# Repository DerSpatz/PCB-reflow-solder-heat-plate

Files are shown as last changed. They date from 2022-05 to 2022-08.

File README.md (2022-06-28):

# PCB reflow solder heat plate

## Introduction

The PCB reflow solder heat plate can be used to solder small PCBs with SMD parts. The user can control the maximum temperature and heating curve.

## Hardware design

The idea for this design comes from https://github.com/AfterEarthLTD/Solder-Reflow-Plate. But when I checked the original design, I found some issues that could cause safety problems and other design choices that are not optimal.

### Feature list

- PCB size 100x100mm, heat plate size 81x69mm
- DC barrel plug (5.5x2.5mm), runs with 12V/5A power supply
- resettable 5A PTC fuse
- inrush current limiter to protect power supply when capacitors are discharged
- 2.7mF input power filter for smooth current draw
- capacitor discharging resistors
- ATMEGA4809 MCU, can be programmed via UPDI header
- high power NMOS with gate driver circuit
- flyback diode connected to the heat plate
- AMS1117 LDO
- additional diodes for protection
- dual buttons
- status LED
- 0.91" OLED display
- LMT85 analog temperature sensor as main sensor
- option to add additional digital sensors for calibration purposes

### Building your own

You can order almost all parts needed from LCSC/JLCPCB. Only the OLED display and the power supply need to be sourced elsewhere. The BOM includes LCSC part numbers for hand soldering and their automated SMT manufacturing. Minimal part size is 0805 and there's enough space between all solder pads, so hand soldering should be no problem if you have a steady hand. Hardest part will be the MCU, but this is hand solderable, too.

### Safety measures compared to the original design

The original design had a too low heat plate resistance, which caused very high current spikes when the heat plate was turned on. This should be filtered by PWM and the input capacitors, but the input capacitor in the original design was far too small (100µF). Because of this, the fuse always blew when the device was turned on, so eventually the fuse was removed again.
In my design I made the input capacitors 27 times larger to have a smoother current draw. I also added a fuse, and an inrush current limiter. After disconnecting the power supply, the output capacitors are quickly discharged to GND.
The original also had no gate driver, so the NMOS was only driven with logic levels. I added a simple NPN gate driver.
Switching inductive loads (like the long heat plate trace) causes voltage spikes. In the original design, the filtering was done with an ESD diode and a small capacitor. The usual way to filter these voltage spikes is a flyback diode.
The resistance of the heat plate was very low, so the current draw with 100% PWM duty cycle was very high. If the MCUs hangs up and the power MOSFET stays active, the original design could cause too much stress for the power supply. Furthermore, even with a hot heat plate, the resistance would still be so low that the board would draw more than 5A.
In my design, the heat plate resistance was chosen in a way that a hot heat plate will draw less than 5A, so it is much safer to run the new design, as it will automatically reach electrically safe working conditions.

## Firmware

The original firmware was reworked by Nathan Heidt (https://github.com/heidtn) and works mostly, only the temperature sensing is incorrect (as the firmware was written with an earlier board revision). So for now, you just need to unplug the device when the PCB that needed soldering is done. Also, the dual color LED is not yet included into the code, for now it just lights green to show power. And the buttons sometimes don't react properly.

Daniel Oltmanns (https://github.com/oltdaniel) is doing a rework of the firmware using platformio.

### To-do list for software:
- use of the dual color LED (green = power, orange = heating, red = hot)
- better temperature sensing
- better working buttons
- calibration function for the analog temperature sensor by taping a digital probe directly to the heat plate

Please note that I can only do hardware design, so I can't contribute anything to the software. 

### Programming the MCU

The MCU can be programmed with JTAG2UPDI (https://github.com/ElTangas/jtag2updi). For programming, you need an Arduino with ATMEGA328p (Uno or Nano), some wires, a 4.7k resistor and  a 10µF capacitor or 120 Ohm resistor to disable the auto-reset.

JCM from the Discord explained the process pretty good:

> 1. Download/Clone this project: https://github.com/ElTangas/jtag2updi and rename the folder "source" to "jtag2updi" (otherwise the Arduino IDE won't like it)
> 2. Open jtag2updi/jtag2updi.ino in your Arduino IDE
> 3. Configure the flasher options for your Arduino Nano and flash it
> 4. Connect D6 of your Arduino Nano over the 4.7kOhm resistor to the UPDI pin of the board and 5V to 5V and GND to 0V
> 5. Add the MegaCoreX hardware package to the Ardunio IDE (see https://github.com/MCUdude/MegaCoreX#how-to-install)
> 6. Install the Adafruit_GFX, Adafruit_SSD1306, DallasTemperature and Debounce2 libraries with the Library Manager (you might not need all of them depending on which firmware you plan to use)
> 7. Download and open the ino you want to upload to the ATMEGA4809 (https://github.com/DerSpatz/PCB-reflow-solder-heat-plate/blob/main/Firmware/pcb_reflow_fw/pcb_reflow_fw.ino)
> 8. Select the options for the programmer (Board: ATmega4809, Clock: Internal 16 MHz, BOD: 2.6V or 2.7V, EEPROM: retained, Pinout: 48 pin standard, Reset pin: Reset, no Bootloader) and select the port of your Ardunio Nano as Port
> 9. Select Burn Bootloader and see if it runs through
> 10. Temporarily disable auto reset for the Arduino Nano: https://playground.arduino.cc/Main/DisablingAutoResetOnSerialConnection/ (not sure if it's needed for the Nano, it was for my Mega)
> 11. Select Sketch > Upload using Programmer (normal Upload will not work)

## Thanks

Special Thanks go out to:

Nathan Heidt for writing the software and testing

Merlin Shaw (www.facebook.com/GeekIslandGaming) for ordering the first batch of prototypes and testing

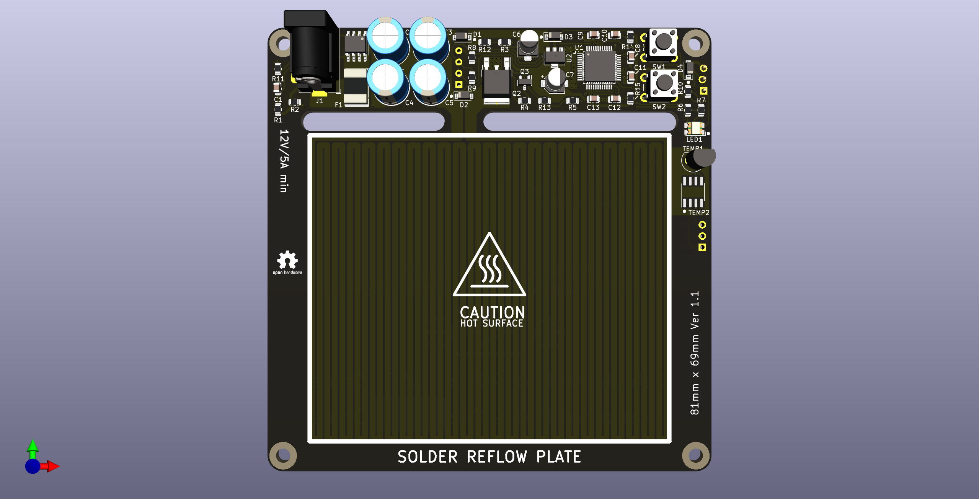
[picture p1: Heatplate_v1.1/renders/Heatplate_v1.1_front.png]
heatplate PCB front

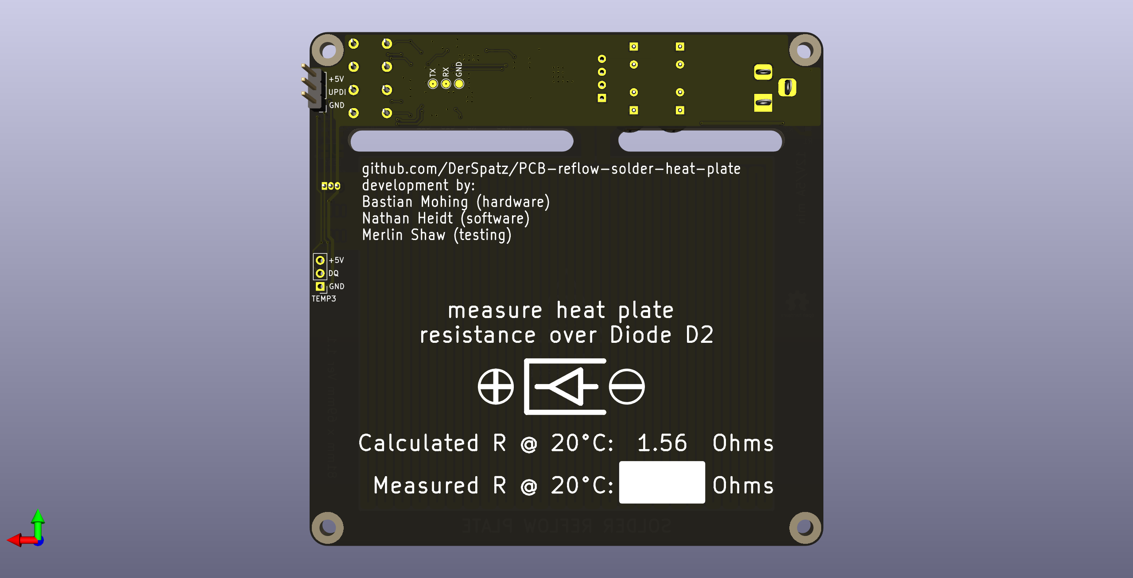
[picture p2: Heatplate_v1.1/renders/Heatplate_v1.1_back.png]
heatplate PCB back


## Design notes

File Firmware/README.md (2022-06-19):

# PCB reflow firmware
This firmware is for the PCB reflow hotplate designed by Spatz.

It has the following features:
- reflow profiles
- OLED display
- profile PID tracking
- temperature setpoint tracking
- safe voltage calculation
- memory validation 

## Build and load process
to build and load, you need a UDPI programmer and core definitions for the Atmega4809.

If you don't have a UDPI programmer you can use another arduino like in this link:
https://github.com/ElTangas/jtag2updi 

You can download the Atmega4809 definitions here:
https://github.com/MCUdude/MegaCoreX/tree/master

Make sure the DallasTemperature and Adafruit display libraries are installed. 

build and load through the arduino IDE as normal.  Select the Atmega4809 as the target
and make sure the correct programmer is selected.

## TODO

- Needs a good amount of cleanup and refactoring
- Has a hack estimation for minimum PWM, need to find a way to improve this
- should switch buttons to bounce2
- if there's no current sense, write a function to approximate resistance based on temperature
- validate temperature estimation function is correct across multiple boards

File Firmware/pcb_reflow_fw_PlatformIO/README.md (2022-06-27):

# Firmware

This firmware project structure is based on [PlatformIO](https://platformio.org/).
The flashing has been configured to use an Arduino as a programmer using the
following project: https://github.com/ElTangas/jtag2updi.

## Todo

- [ ] Split main file into multiple ones _(makes it easier to work on)_
- [ ] Better Instructions for flashing.

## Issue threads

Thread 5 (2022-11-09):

Idea: use an NTC thermistor for sensing the heat-plate temperature

DominikPalo, 2022-11-09:
The current design uses an LMT85 analog temperature sensor as the main sensor. As this sensor is not directly attached to the heated area (and can't be due to its limited temperature range –50°C to 150°C), the temperature measurements are not very precise and tend to be skewed/affected by the airflow around the sensor.

So, my idea is to use a 100K NTC thermistor instead. The thermistor would be attached directly to the bottom side of the heating area (by a piece of Kapton tape). Such NTC thermistors are very popular in 3D printers for sensing both the hot end and heated bed temperatures and therefore cheap and widely available. They are precise and can easily measure temperatures up to 300°C, so I think they would be a right fit for this project too.

The connection to the MCU is very simple - just a couple of resistors and a capacitor connected to a single ADC input. Here is an example connection from the [BTT SKR Mini E3 board](https://github.com/bigtreetech/BIGTREETECH-SKR-mini-E3/blob/master/hardware/BTT%20SKR%20MINI%20E3%20V1.2/BTT%20SKR%20mini%20E3%20V1.2sch.pdf):
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

gifter77, 2023-03-19:
It's pretty easy to do without any change to the PCB. Just connect your NTC thermistor between temp3 data and GND pins, optionally change R10 to something that works better as a resistance divider with your thermistor and change the temperature calculation code.
See how I have done it below. I'm using a 10K 3950 thermistor and I've changed R10 to 1k instead of 4.7K to get a better range in the ADC.
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

jgoldwein, 2023-03-20:
Great idea.  Have you changed the code too?  If so, what changes did you make?

VTeselkin, 2023-05-18:
Great idea, has anyone made changes to the code?

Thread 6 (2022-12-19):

Are drain and source of inrush limiter mosfet reversed?

MRo47, 2022-12-19:
thanks for sharing this.
I'm a newbie on mosfets. But should the drain and source of inrush limiter mosfet be reversed? I've read it doesn't matter much but unsure.
Or is there a good reason why they are kept as such?
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

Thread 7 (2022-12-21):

Make Centroid (Pick and Place) files available

Tyler135441, 2022-12-21:
For some reason I am unable to open the Kicad project to create a centroid file as I am not sure how to get it from github in a non text file format. Kicad is new to me so this may be my issue, but I still think it is a good idea to upload some centroid/pickandplace files in the form of a csv file for easily getting it pre soldered from pcb manufacturers like PCBWay or JLPCB.

Tyler135441, 2023-01-17:
For some reason when I downloaded the whole project natively the kicad files seemed to be corrupted or something and would not open in kicad, however when I downloaded on a separate device and moved it over via usb drive they seem to be fine. I have no idea. I still think having the centroid files in a csv on the repository would be nice though since it may circumvent any similar witchcraft in the future and simply provide greater ease of access.

Closed 2023-01-17.

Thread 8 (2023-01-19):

Low resistance Heatplates - not getting hot

ManCloud, 2023-01-19:
Hello,

I have a little Problem: i ordered 15 boards qt JLCPCB and they all seem to have too low resistance values.
I measured boards with about 1.34 ohms which work kinda fine but also have boards at 1.12ohms that do not.

If i put the resistance inside the firmware to 1.10ohm, the board will heat up until about 70°C and then constantly reduce the current until about 250mA and that's it...

and it i put the resistance to 1.12 ohm the board will surpass the 5A mark, which somehow makes my PSU shutting down (even though the >1.34ohm boards also surpass 5A but without shutting down).

I'm kinda clueless where to start debugging here 😅

This was part of a "community order" and not a "for profit thing".

bwack, 2023-02-24:
How is it going with the project. I'm about to build this myself. No expereince, though did you measure using a four wite technique? (Two wires Pass a constant current, two wires measure voltage)

ManCloud, 2023-02-24:
No, I modified a resistance meter I used in the past for coil resistance measurements for my vape

bwack, 2023-02-24:
I don't see any replies from the maintainer here. Maybe I can have a look at the code this weekend.

ManCloud, 2023-02-24:
That would be nice! I already wanted to have a look myself but am pretty busy with other stuff 🙈

bwack, 2023-03-03:
I'm experiencing overcurrent. I'm feeding in 12V from my lab power supply set to limit current at 5A. It doesn't take long for the regulator to go beyond that limit.
I've had no luck in getting the serial debugging data, so I display the PWM value on the screen in real time. It shows that the PWM value drops down to 0 (100% power)  after just a few maybe 10 seconds.. 12V into ~1 Ohm is way too much.
Not sure what to do about this yet. The board does monitor the input voltage. I could try in software to find out what how low PWM can get before the supply voltage starts to drop, with consideration that cable and contacts will drop a lot of voltage as well.

bwack, 2023-03-07:
My video on this board. https://youtu.be/bX83ZVMr6Pg

Findings. Resistance is too low to produce heat up quick enough at sensible current levels (5A). This cannot be fixed without reducing the trace width, or putting more current into and removing the 5A PTC fuse. There is no current sensing.

 It goes way beyond 5A. My bench powersupply droppet the voltage to 7V at 5A constant current  though rised to 10V when melting tin hot. But slowly. The 7V drops to about 6V at the heating bed.

I was thinking of doing my own board by tuning the heatbed to accept 24 or perhaps 19V (60W lsptop PSUs) to get the current down to 3 or 2.5A. Adding current sense. Measure resistance of the bed in real time to calculate temperature. But people are too negative, and so limited use case, I don't bother with this project I think.

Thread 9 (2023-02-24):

Tempted to start: is someone working on the issues on the to-do-list? Just to know.. Many thanks!

ik0adr, 2023-02-24:
Many thanks!!

bwack, 2023-02-24:
I'm finally building the hotplate 1.1 after a long pause. I'll give some feedback If I find anything worth mentioning. Ps I'm planning to do a youtube video as well.

ik0adr, 2023-03-01:
I am just waiting for PCB and components.
Will appreciate youtube video!!
Cheers

ik0adr, 2023-04-03:
Hi all.
I am waiting for some components to finish the DerSpatz plate.
I do have some questions thow..
Is the firmware on GitHub doing the reflow curve control?
In readme they say the temperature sensing is incorrect..
I thought the thermistor mod would solve that.
Am I wrong?
Cheers, have a nice day

Berkays, 2023-05-21:
Feel free to check out my stm32 board implementation at [repository](https://github.com/Berkays/ReflowPlate) which should hopefully has a more organized source structure and some improvements like ntc, rotary encoder input etc.

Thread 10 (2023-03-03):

Component base for self-assembly

VTeselkin, 2023-03-03:
Hello. Ordered a fee. Some notes on the component base: capacitors C6 and C7 could be made ordinary and not smd, this would reduce the number of component suppliers for those who order them from Aliexpress, for example. The two-color LED1 is generally an extremely rare component in this size, it was easier to make two small separate LEDs. Temperature sensors could be placed on the other side of the board in the center of the table, at least one of the three.

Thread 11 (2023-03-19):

Made slight code changes to take advantage of Red LED... plus some design suggestions

jgoldwein, 2023-03-19:
Hello and thank you for this amazing project.  I have now built 5 of these, all using JLCPCB boards and LSCS components that I have been able to solder on to the boards.  I have also made some slight improvements in the firmware code which I have forked and posted at https://github.com/jgoldwein/PCB-reflow-solder-heat-plate/blob/main/Firmware/pcb_reflow_fw/pcb_reflow_fw.ino.

A few suggestions:
1. Primarily, if there were a way to **separate/detach the heating surface from the primary electronics** (not including the temperature sensor), the utility of the reflow plate would increase significantly.  I find that after about 5-10 uses the heating panel deteriorates beyond its usefulness.   And, since the Dallas 1-wire temperature sensor is not being used, replacement would only require LMT85 replacement provided that the LED and R6,7 could be moved on to the main circuit board.
2. I did see a comment suggesting substitution of parts such as 2 separate LEDs in place of the one bi-LED component.  Makes sense to me, but probably relatively easy to do without changing the PCB layout.
3. No problem from my perspective using the ATMEGA4809-AFR.  Readily available and inexpensive from many vendors such as DigiKey and Mouser in my area (USA).  Took a bit of work to figure out the UPDI programming, but a positive experience for me.

Thanks again for designing this.  It is really appreciated and has been extremely useful to me.

JG

gifter77, 2023-03-19:
I believe the heating panel deteriorates quickly because it actually gets way hotter than what the LMT85 measures. Even when set to 140C I measured over 200C on the heatplate. An easy solution is to use an NTC thermistor stuck under the heatplate instead of the LMT85.

jgoldwein, 2023-03-19:
Good idea, but I know that solder melting for reflow does not seem to occur until after 1:40 or so for solder that has a 138° melting point on my system. I think we need to factor in the r values of any material such as PCBs that are in involved.

Still, I think it would be a good idea if we could detach the heating plate and replace it easily rather than the current design. With constant heating, cooling, and reheating, I can't help but think that there will inevitably be some deterioration of the heating plate.

Thank you kindly for responding to my comment. I think again that this is a great product and just want to make it even better.

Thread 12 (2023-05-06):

How many heating cycles does the PCB survive?

manuel-rw, 2023-05-06:
Hello everyone,
I want to get into SMD soldering.
Can anyone tell me, how many cycles / thermal stress this PCB usually survives, until it deteriorates?
I know that many factors will influence this, but it would be useful to get a general idea what to expect.

Thank you!
Best regards

manuel-rw, 2023-05-09:
Hi, thanks for the reply.
Since the heating PCB is not replaceable, what endurance are you getting with the IR?
It shocked me seeing people mentioning only 5 cycles, but I'm not sure how accurate that is.

bwack, 2023-05-09:
I think the 5 cycles is due to the huge temperature swings causing it to overheat.

I haven't used mine more than maybe 10 times, but the pcb is still holding up. no warping.

bwack, 2023-05-09:
Here is a video of my experimentation with IR sensor.
https://www.youtube.com/watch?v=z8zI6PzrAY8

manuel-rw, 2023-06-06:
Thanks @bwack for answering.
I think I will stick with my hot air gun for now.
Closing this issue since it's resolved :)

Closed 2023-06-06.

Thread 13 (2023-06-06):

What package for the LM1117?

crazyelectron-io, 2023-06-06:
I'm trying to figure out what package is used for the LM1117 LDO because the SOT-223 package they usually come in is too large for the PCB footprint.
A link to an example part would be great.

Closed 2023-06-06.

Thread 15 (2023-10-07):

Open 'Discussions' for repo

platima, 2023-10-07:
Hey want to open this up so suggestions like ATmega328p compatibility can be put there, as opposed to being an issue?

For now, I'll add some 'issue' suggestions, but can move them to a discussion later.

See how I have setup https://github.com/platima/ESP32-CX-Riser/discussions as a good example. Cheers!

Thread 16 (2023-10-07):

USB-C power connector

platima, 2023-10-07:
Since USB-C is the defacto standard these days, can do 20V @ 5A, and means I don't have to buy more barrel jacks

platima, 2023-10-07:
STUSB4500 looks like a good USB-C controller, and is used by https://www.sparkfun.com/products/15801, but LCSC stock appears quite low.

onsemi FUSB302BVMPX looks like a very good alternative, with plenty of stock, and a fraction of the price.

The USB connection could also then be used for flashing the ATmega328P/4809 if you have someone modify the software to also include a bootloader, aka so it works like a jtag2updi programmer AND runs the heating firmware, since there are plenty of IOs spare.

https://github.com/ReclaimerLabs/USB-PD-Breakout has this integrated nicely already it appears!

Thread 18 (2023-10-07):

No mention of PCB type it seems

platima, 2023-10-07:
Assuming 1.6mm FR4, but I cannot see this specified anywhere. Apologies if I just missed it.

platima, 2023-10-07:
I found 1.51mm (?) FR4 specified in the PCB file, but that is definitely an odd thickness.

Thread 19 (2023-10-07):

Copper thickness on PCB not specified

platima, 2023-10-07:
The KiCad PCB setup has 0.035mm (1 oz) but that seems very thin. Although that'd create more resistance and heat, and it's much cheaper to order. Thought it best to check before ordering.

Probably worth specifying this with board thickness in the README.md

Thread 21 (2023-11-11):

Not working at all. Immediate blows the 1117

arwidcool, 2023-11-11:
Has anyone actually built this?

As soon as i give it power it blows the 1117. When i power the Atmega just from 5v it works. Double, triple and 5x checked component placement and its all per v1.1

arwidcool, 2023-11-12:
Found the issue, apparently the sot89 casings have many different pin configurations for LDO.

And the main mosfet the IRLR8726TRPBF was bad and might not be optimal.

So make sure you get the correct SOT-89 LDO and an alternate to the IRLR8726TRPBF that works is AOD4184A.

Closed 2023-11-12.

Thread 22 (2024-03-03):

Spare boards for sale here

platima, 2024-03-03:
Listed spares I had made up, at cost, for anyone that wants them: [https://shop.plati.ma/products/derspatz-pcb-solder-reflow-heat-plate-v1-1](https://shop.plati.ma/products/derspatz-pcb-solder-reflow-heat-plate-v1-1)

Podex12, 2024-03-22:
do you also sell the assembled version? if so, what's the price? from where did you send it (what country)? can you send via international EMS (or any cheap shipping)?

platima, 2024-03-22:
Nah haven't had any assembled. At a glance, they'd likely be about $30 AUD each. Shipping here is all via Australia Post, as there are no courier services this regional, so about $13 to the US international standard.

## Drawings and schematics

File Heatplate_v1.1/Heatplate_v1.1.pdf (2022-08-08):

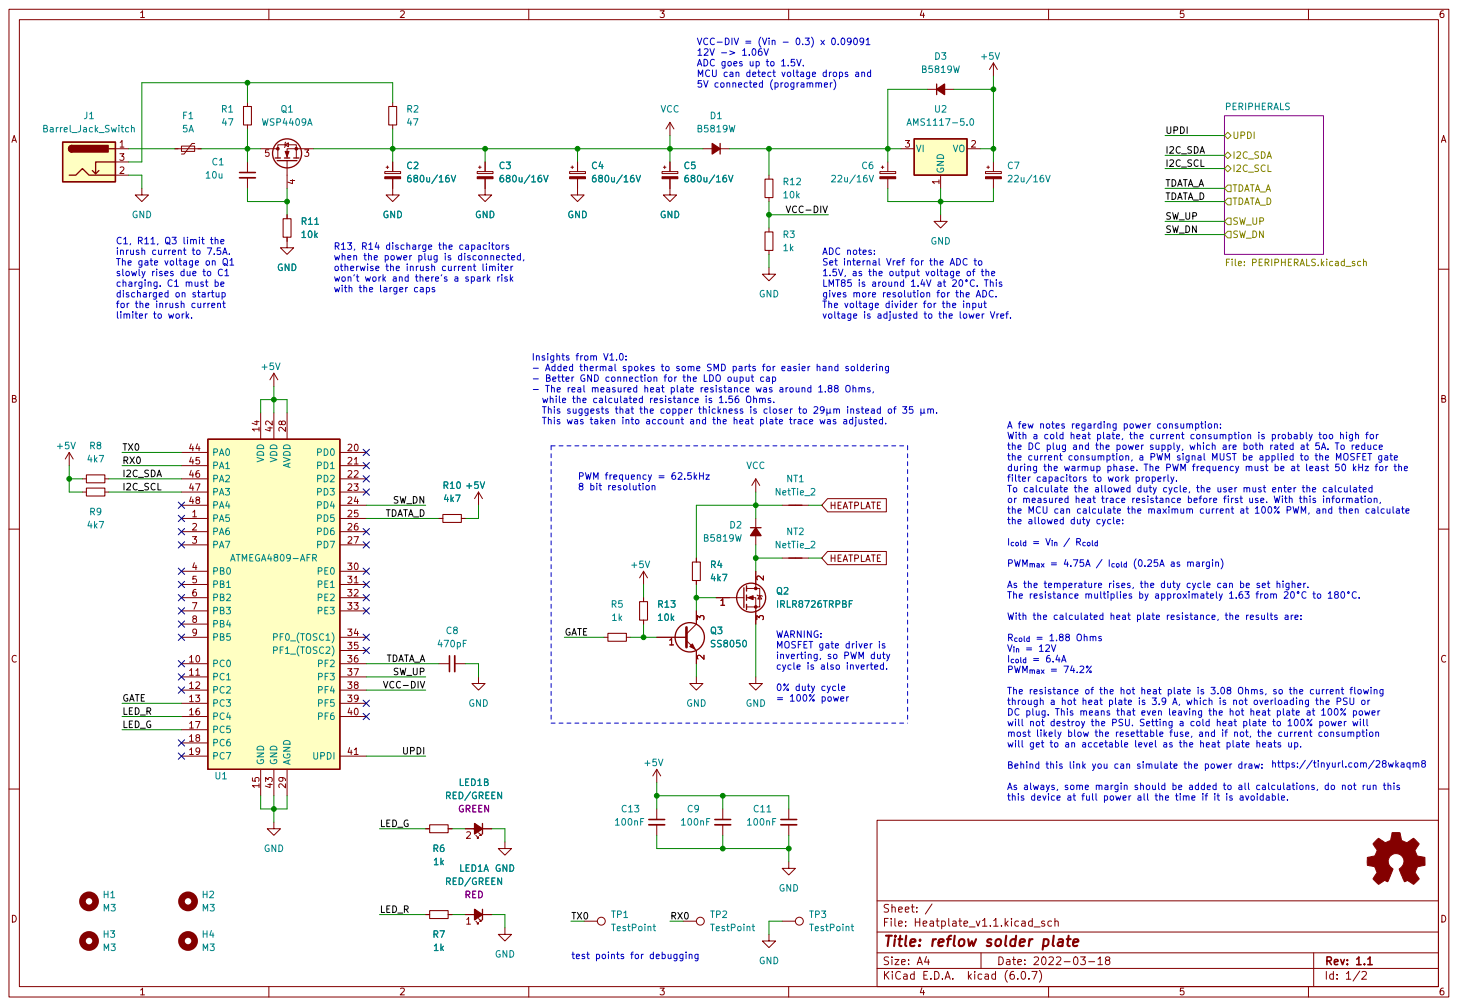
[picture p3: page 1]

VCC-DIV = (Vin - 0.3) x 0.09091
ADC goes up to 1.5V.
MCU can detect voltage drops and
5V connected (programmer)

R13, R14 discharge the capacitors
when the power plug is disconnected, otherwise the inrush current limiter won't work and there's a spark risk

This was taken into account and the heat plate trace was adjusted. C1, R11, Q3 limit the
inrush current to 7.5A. The gate voltage on Q1

ADC notes: Set internal Vref for the ADC to 1.5V, as the output voltage of the

slowly rises due to C1
charging. C1 must be
discharged on startup
for the inrush current
limiter to work.

with the larger caps

gives more resolution for the ADC.
The voltage divider for the input
voltage is adjusted to the lower Vref.

Insights from V1.0:
- Added thermal spokes to some SMD parts for easier hand soldering
- Better GND connection for the LDO ouput cap
- The real measured heat plate resistance was around 1.88 Ohms,
while the calculated resistance is 1.56 Ohms. þÿ  This suggests that the copper thickness is closer to 29µm instead of 35 µm.

A few notes regarding power consumption:
With a cold heat plate, the current consumption is probably too high for
the DC plug and the power supply, which are both rated at 5A. To reduce
the current consumption, a PWM signal MUST be applied to the MOSFET gate
during the warmup phase. The PWM frequency must be at least 50 kHz for the
filter capacitors to work properly.
To calculate the allowed duty cycle, the user must enter the calculated or measured heat trace resistance before first use. With this information,

PWM frequency = 62.5kHz 8 bit resolution

the MCU can calculate the maximum current at 100% PWM, and then calculate
the allowed duty cycle:

PWM_{max} = 4.75A / I_{cold} (0.25A as margin)

As the temperature rises, the duty cycle can be set higher.

With the calculated heat plate resistance, the results are:

this device at full power all the time if it is avoidable. WARNING: MOSFET gate driver is

inverting, so PWM duty
cycle is also inverted.

The resistance of the hot heat plate is 3.08 Ohms, so the current flowing
through a hot heat plate is 3.9 A, which is not overloading the PSU or
DC plug. This means that even leaving the hot heat plate at 100% power
will not destroy the PSU. Setting a cold heat plate to 100% power will
most likely blow the resettable fuse, and if not, the current consumption
will get to an accetable level as the heat plate heats up.

Behind this link you can simulate the power draw:

As always, some margin should be added to all calculations, do not run this

File: Heatplate_v1.1.kicad_sch Sheet: /
Id: 1/2 Title: reflow solder plate

test points for debugging

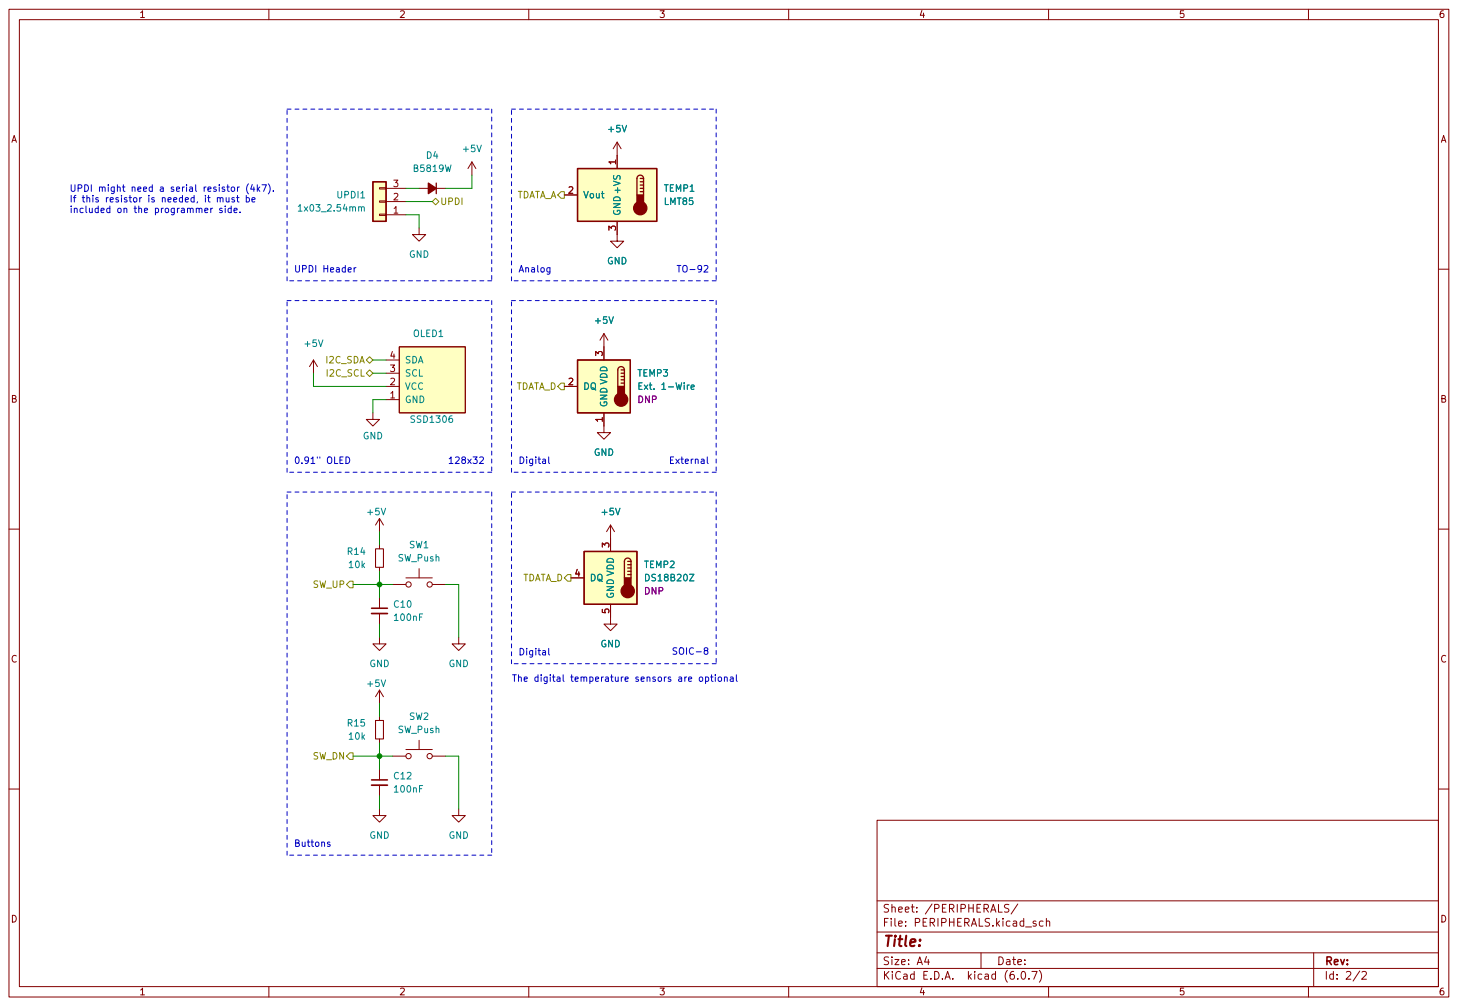
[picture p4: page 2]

UPDI might need a serial resistor (4k7).
If this resistor is needed, it must be

3 TEMP3 Ext. 1-Wire DNP VDD
TEMP3 Ext. 1-Wire DNP GND

File: PERIPHERALS.kicad_sch Sheet: /PERIPHERALS/ GND

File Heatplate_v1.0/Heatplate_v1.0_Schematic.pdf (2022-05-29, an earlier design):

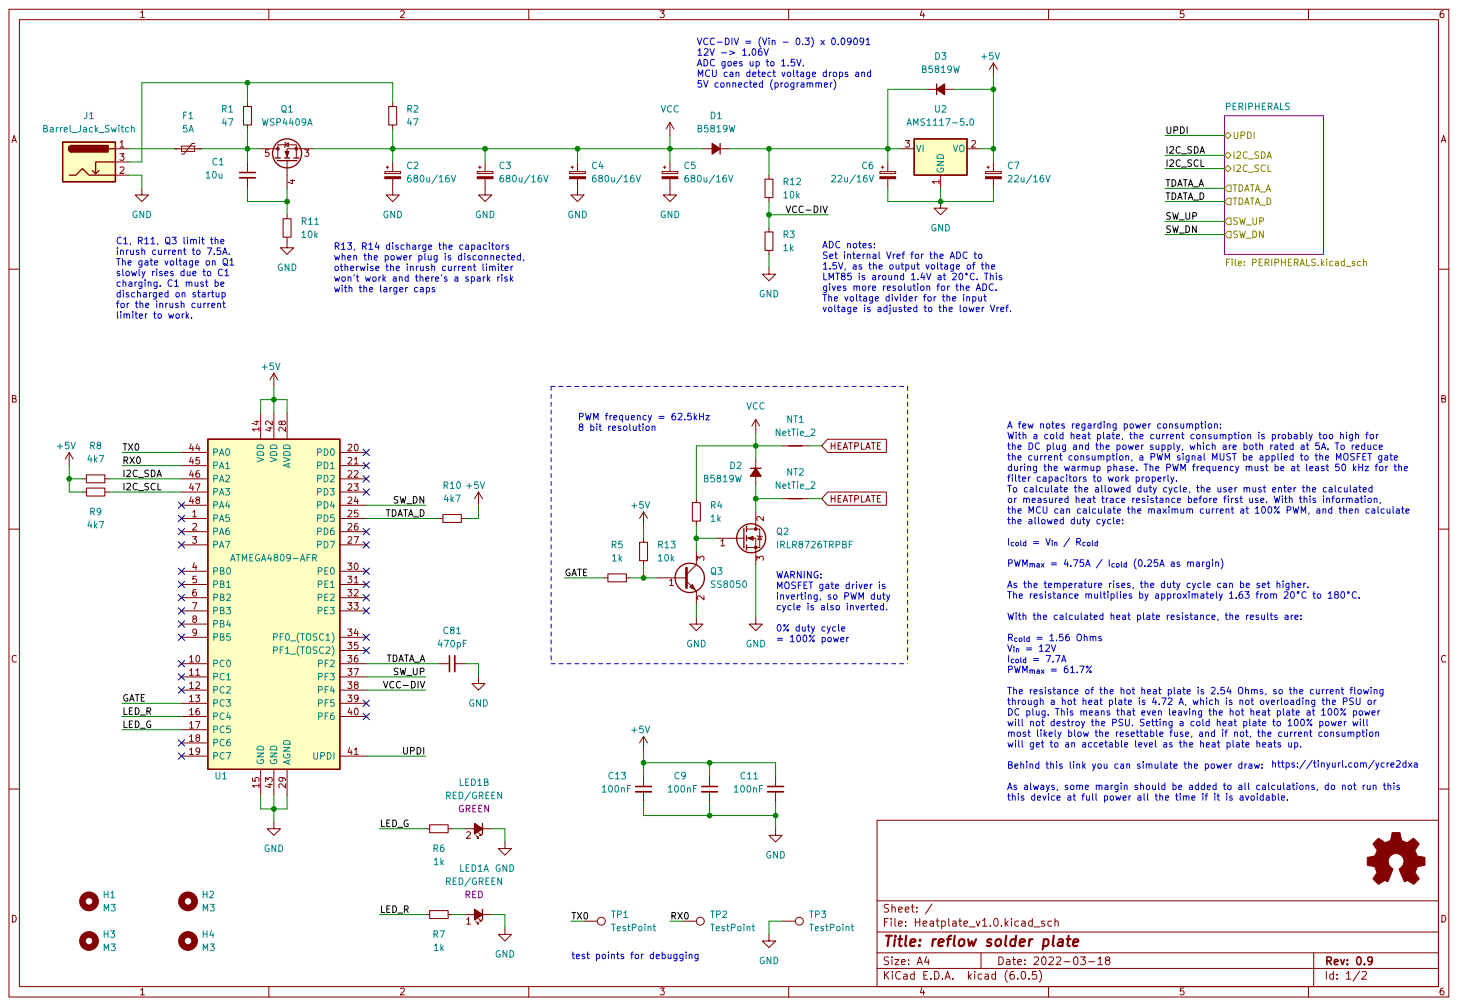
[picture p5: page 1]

VCC-DIV = (Vin - 0.3) x 0.09091
ADC goes up to 1.5V.
MCU can detect voltage drops and
5V connected (programmer)

voltage is adjusted to the lower Vref. C1, R11, Q3 limit the
inrush current to 7.5A. The gate voltage on Q1

PWM frequency = 62.5kHz 8 bit resolution R13, R14 discharge the capacitors
when the power plug is disconnected, otherwise the inrush current limiter won't work and there's a spark risk

slowly rises due to C1
charging. C1 must be
discharged on startup
for the inrush current
limiter to work.

gives more resolution for the ADC.
The voltage divider for the input

A few notes regarding power consumption:
With a cold heat plate, the current consumption is probably too high for
the DC plug and the power supply, which are both rated at 5A. To reduce
the current consumption, a PWM signal MUST be applied to the MOSFET gate
during the warmup phase. The PWM frequency must be at least 50 kHz for the
TP3 TestPoint NT2 NetTie_2 GND

filter capacitors to work properly.
To calculate the allowed duty cycle, the user must enter the calculated or measured heat trace resistance before first use. With this information,

the MCU can calculate the maximum current at 100% PWM, and then calculate
the allowed duty cycle:

PWM_{max} = 4.75A / I_{cold} (0.25A as margin)

https://tinyurl.com/ycre2dxa WARNING: MOSFET gate driver is

As the temperature rises, the duty cycle can be set higher.

inverting, so PWM duty
cycle is also inverted.

With the calculated heat plate resistance, the results are:

The resistance of the hot heat plate is 2.54 Ohms, so the current flowing
through a hot heat plate is 4.72 A, which is not overloading the PSU or
DC plug. This means that even leaving the hot heat plate at 100% power
will not destroy the PSU. Setting a cold heat plate to 100% power will
most likely blow the resettable fuse, and if not, the current consumption
will get to an accetable level as the heat plate heats up.

Behind this link you can simulate the power draw:

As always, some margin should be added to all calculations, do not run this
this device at full power all the time if it is avoidable.

File: Heatplate_v1.0.kicad_sch Sheet: /
Id: 1/2 Title: reflow solder plate

test points for debugging

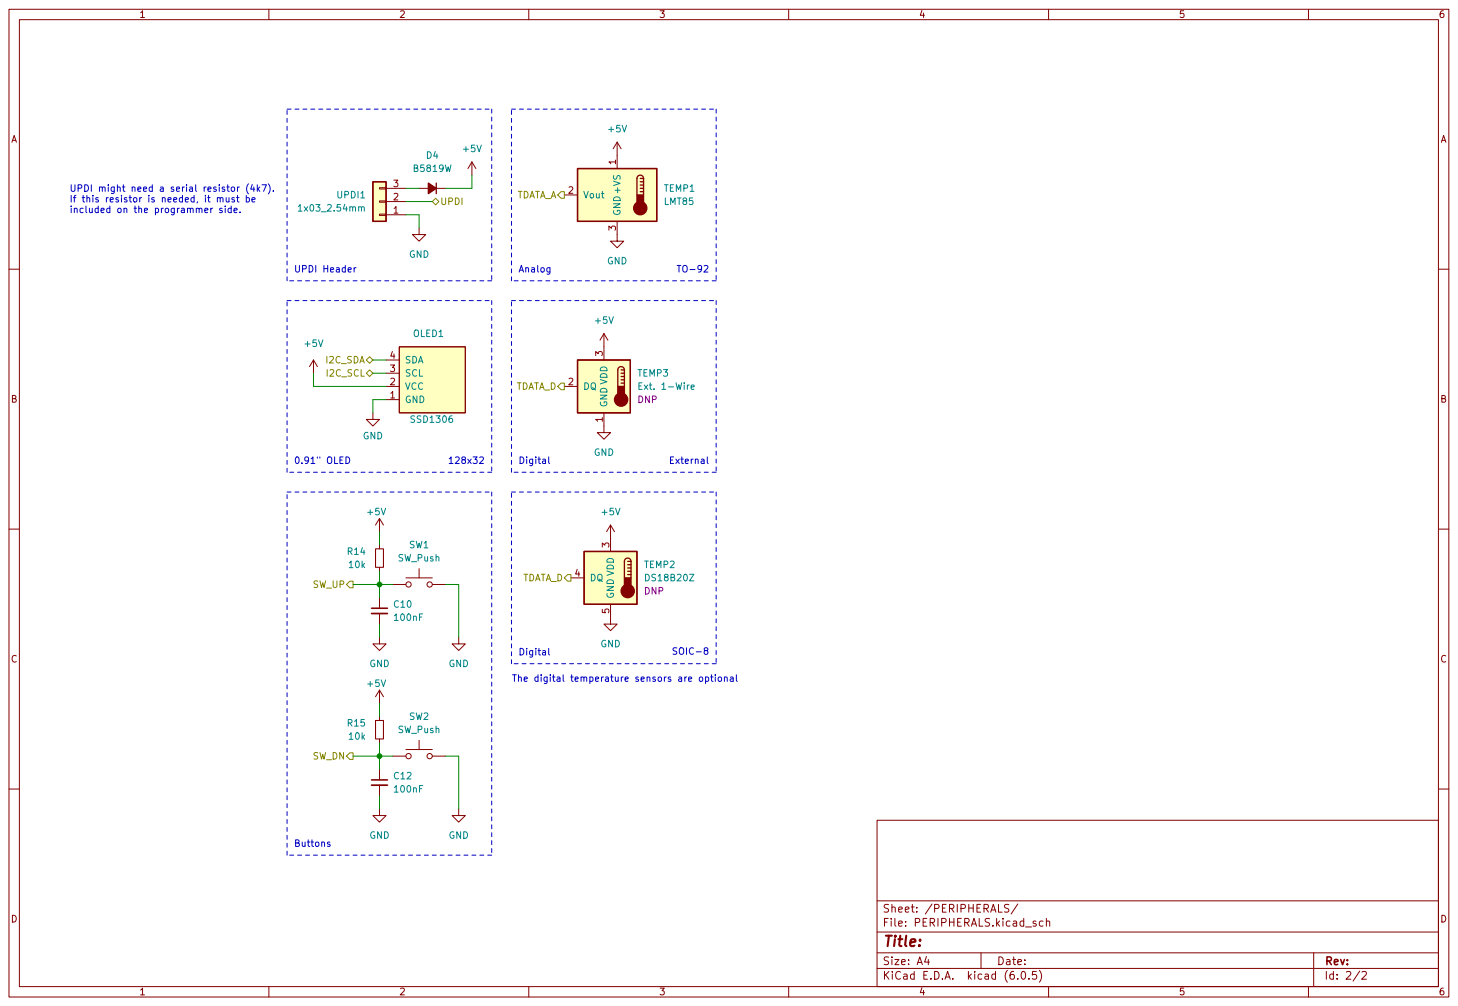
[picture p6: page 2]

UPDI might need a serial resistor (4k7).
If this resistor is needed, it must be

3 TEMP3 Ext. 1-Wire DNP VDD

File: PERIPHERALS.kicad_sch Sheet: /PERIPHERALS/ C10

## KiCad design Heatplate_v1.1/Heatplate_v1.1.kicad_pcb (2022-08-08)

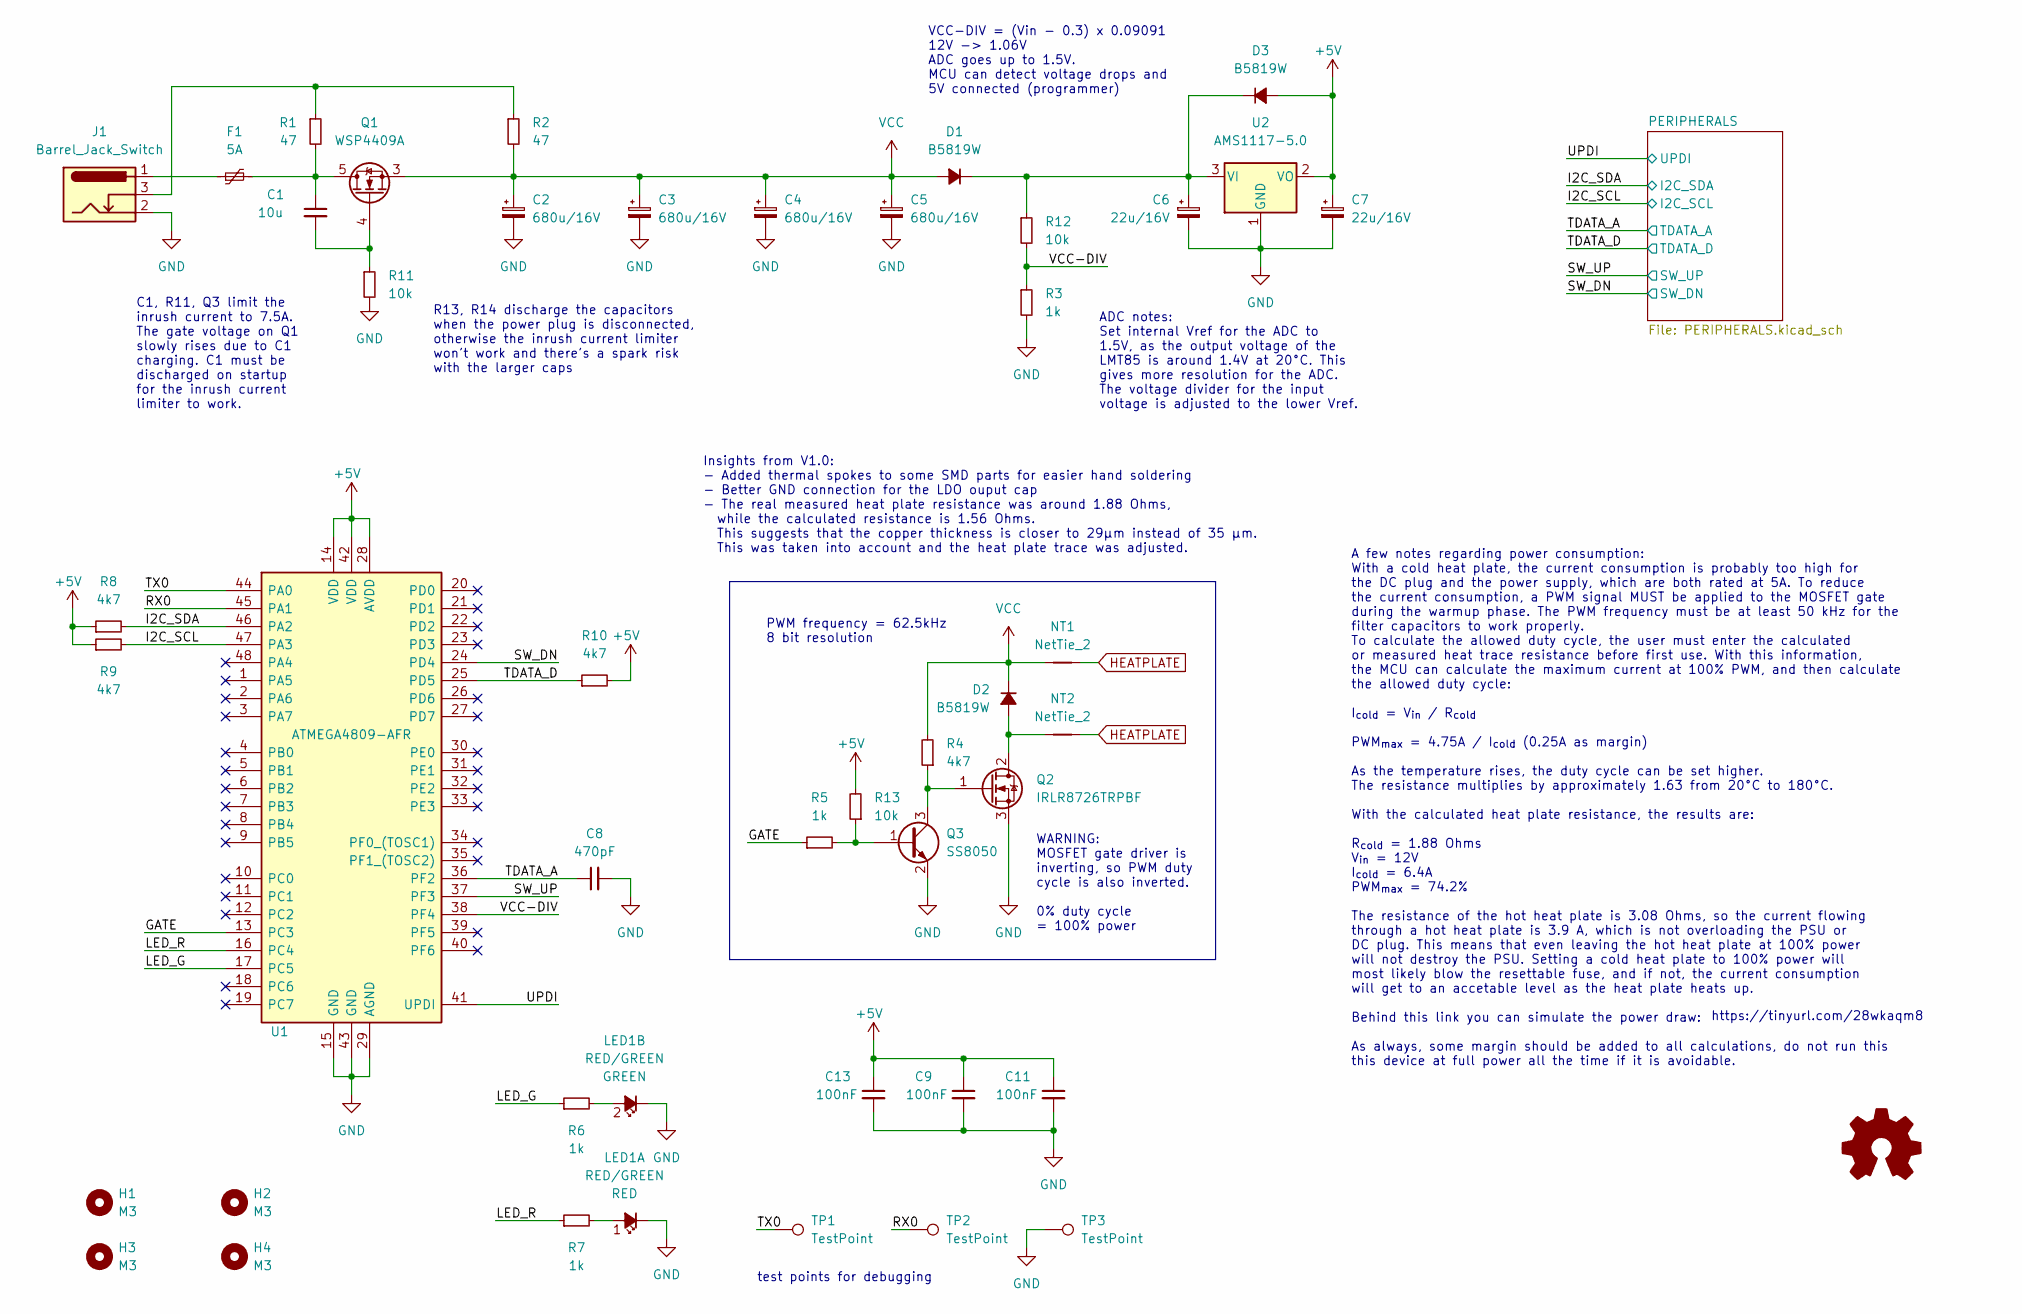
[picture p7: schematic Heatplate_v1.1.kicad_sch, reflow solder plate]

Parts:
C1: 10u; C_0805_2012Metric; LCSC Part Number C2922480
C2, C3, C4, C5: 680u/16V; CP_Radial_D8.0mm_P3.50mm; LCSC Part Number C88760
C6, C7: 22u/16V; CP_Elec_4x5.4; LCSC Part Number C88799
C8: 470pF; C_0805_2012Metric; LCSC Part Number C1743
C9, C11, C13: 100nF; C_0805_2012Metric; LCSC Part Number C1711
D1, D2, D3: B5819W; D_SOD-123; LCSC Part Number C64885
F1: 5A; Fuse_2920_7451Metric; LCSC Part Number C910846
H1, H2, H3, H4: M3; MountingHole_3.2mm_M3; LCSC Part Number C551332
J1: Barrel_Jack_Switch; BarrelJack_Horizontal; LCSC Part Number C381115
LED1: RED/GREEN; LED_Avago_PLCC4_3.2x2.8mm_CW; LCSC Part Number C131251
LOGO1: Logo_Open_Hardware_Small; OSHW-Logo2_7.3x6mm_SilkScreen
NT1, NT2: NetTie_2; NetTie-2_SMD_Pad1.3mm
Q1: WSP4409A; SOIC-8_3.9x4.9mm_P1.27mm; LCSC Part Number C2880527
Q2: IRLR8726TRPBF; TO-252-2; LCSC Part Number C81137
Q3: SS8050; SOT-23; LCSC Part Number C444722
R1, R2: 47; R_0805_2012Metric; LCSC Part Number C17714
R3, R5, R6, R7: 1k; R_0805_2012Metric; LCSC Part Number C17513
R4, R8, R9, R10: 4k7; R_0805_2012Metric; LCSC Part Number C17673
R11, R12, R13: 10k; R_0805_2012Metric; LCSC Part Number C17414
TP1, TP2, TP3: TestPoint; TestPoint_Pad_D1.5mm
U1: ATMEGA4809-AFR; TQFP-48_7x7mm_P0.5mm; Manufacturer_Part_Number ATMEGA4809-AFR; Mouser Part Number 556-ATMEGA4809-AFR
U2: AMS1117-5.0; SOT-89-3; LCSC Part Number C351450

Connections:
+5V: C7.1, C9.1, C11.1, C13.1, D3.2 (A), R8.1, R9.1, R10.2, R13.2, U1.14 (VDD), U1.28 (AVDD), U1.42 (VDD), U2.2 (VO); also elsewhere on the board
/GATE: R5.1, U1.13 (PC3)
/I2C_SCL: R9.2, U1.47 (PA3); also elsewhere on the board
/I2C_SDA: R8.2, U1.46 (PA2); also elsewhere on the board
/LED_G: R6.1, U1.17 (PC5)
/LED_R: R7.1, U1.16 (PC4)
/RX0: TP2.1, U1.45 (PA1)
/SW_DN: U1.24 (PD4); also elsewhere on the board
/SW_UP: U1.37 (PF3); also elsewhere on the board
/TDATA_A: C8.1, U1.36 (PF2); also elsewhere on the board
/TDATA_D: R10.1, U1.25 (PD5); also elsewhere on the board
/TX0: TP1.1, U1.44 (PA0)
/UPDI: U1.41 (UPDI); also elsewhere on the board
/VCC-DIV: R3.1, R12.2, U1.38 (PF4)
GND: C2.2, C3.2, C4.2, C5.2, C6.2, C7.2, C8.2, C9.2, C11.2, C13.2, J1.2, LED1.2 (K1), LED1.4 (K2), Q2.3 (S), Q3.2 (E), R3.2, R11.2, TP3.1, U1.15 (GND), U1.29 (AGND), U1.43 (GND), U2.1 (GND); also elsewhere on the board
HEATPLATE: NT1.2, NT2.2
unnamed: C1.1, F1.2, Q1.5 (D), Q1.6 (D), Q1.7 (D), Q1.8 (D), R1.2
unnamed: C1.2, Q1.4 (G), R11.1
unnamed: C6.1, D1.1 (K), D3.1 (K), R12.1, U2.3 (VI)
unnamed: D2.2 (A), NT2.1, Q2.2 (D)
unnamed: F1.1, J1.1
unnamed: J1.3, R1.1, R2.1
unnamed: LED1.1 (A1), R7.2
unnamed: LED1.3 (A2), R6.2
unnamed: Q2.1 (G), Q3.3 (C), R4.1
unnamed: Q3.1 (B), R5.2, R13.1
VCC: C2.1, C3.1, C4.1, C5.1, D1.2 (A), D2.1 (K), NT1.1, Q1.1 (S), Q1.2 (S), Q1.3 (S), R2.2, R4.2

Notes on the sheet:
C1, R11, Q3 limit the inrush current to 7.5A. The gate voltage on Q1 slowly rises due to C1 charging. C1 must be discharged on startup for the inrush current limiter to work.
VCC-DIV = (Vin - 0.3) x 0.09091 12V -> 1.06V ADC goes up to 1.5V. MCU can detect voltage drops and 5V connected (programmer)
PWM frequency = 62.5kHz 8 bit resolution
A few notes regarding power consumption: With a cold heat plate, the current consumption is probably too high for the DC plug and the power supply, which are both rated at 5A. To reduce the current consumption, a PWM signal MUST be applied to the MOSFET gate during the warmup phase. The PWM frequen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
WARNING: MOSFET gate driver is inverting, so PWM duty cycle is also inverted. 0% duty cycle = 100% power
R13, R14 discharge the capacitors when the power plug is disconnected, otherwise the inrush current limiter won't work and there's a spark risk with the larger caps
https://tinyurl.com/28wkaqm8
test points for debugging
ADC notes: Set internal Vref for the ADC to 1.5V, as the output voltage of the LMT85 is around 1.4V at 20°C. This gives more resolution for the ADC. The voltage divider for the input voltage is adjusted to the lower Vref.
Insights from V1.0: - Added thermal spokes to some SMD parts for easier hand soldering - Better GND connection for the LDO ouput cap - The real measured heat plate resistance was around 1.88 Ohms, while the calculated resistance is 1.56 Ohms. This suggests that the copper thickness is closer to 29µ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

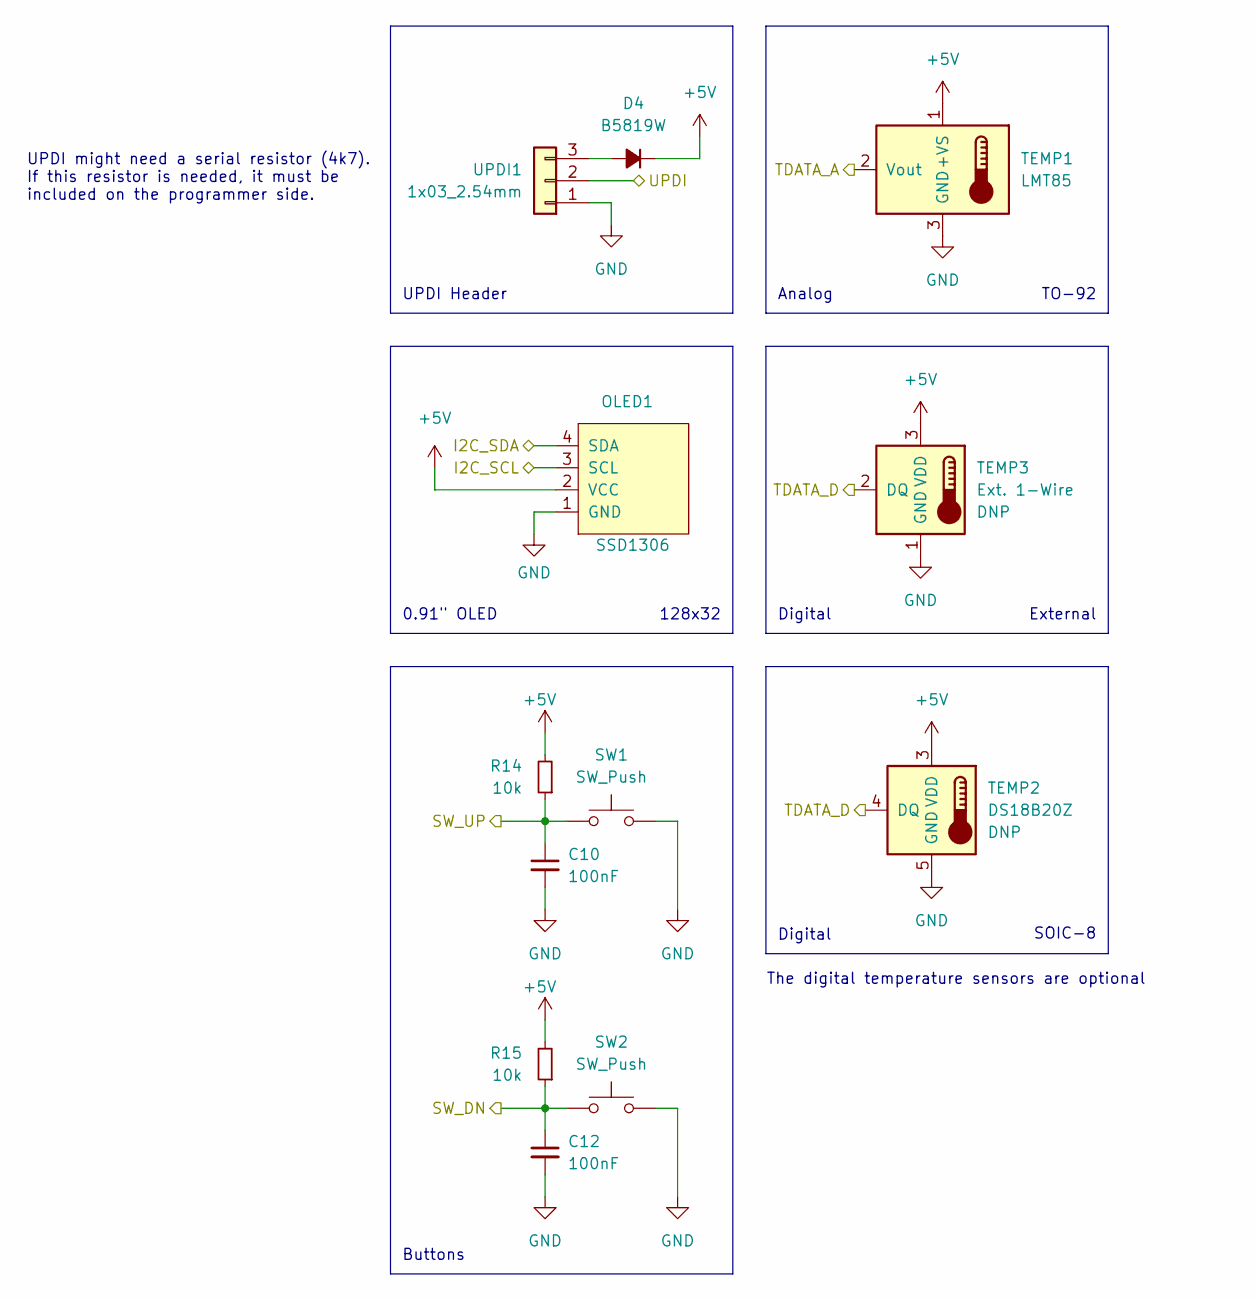
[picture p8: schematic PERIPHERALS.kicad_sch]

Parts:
C10, C12: 100nF; C_0805_2012Metric; LCSC Part Number C1711
D4: B5819W; D_SOD-123; LCSC Part Number C64885
OLED1: SSD1306; 0.91Inch-OLED-Module; LCSC Part Number C2718488
R14, R15: 10k; R_0805_2012Metric; LCSC Part Number C17414
SW1, SW2: SW_Push; SW_PUSH_6mm; LCSC Part Number C136682
TEMP1: LMT85; TO-92_Inline; LCSC Part Number C75856
TEMP2: DS18B20Z; SOIC-8_3.9x4.9mm_P1.27mm; LCSC Part Number C695837
TEMP3: Ext. 1-Wire; PinHeader_1x03_P2.54mm_Vertical
UPDI1: 1x03_2.54mm; PinHeader_1x03_P2.54mm_Vertical; LCSC Part Number C49257

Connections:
+5V: D4.1 (K), OLED1.2 (VCC), R14.2, R15.2, TEMP1.1 (+VS), TEMP2.3 (VDD), TEMP3.3 (VDD); also elsewhere on the board
/I2C_SCL: OLED1.3 (SCL); also elsewhere on the board
/I2C_SDA: OLED1.4 (SDA); also elsewhere on the board
/SW_DN: C12.1, R15.1, SW2.1; also elsewhere on the board
/SW_UP: C10.1, R14.1, SW1.1; also elsewhere on the board
/TDATA_A: TEMP1.2 (Vout); also elsewhere on the board
/TDATA_D: TEMP2.4 (DQ), TEMP3.2 (DQ); also elsewhere on the board
/UPDI: UPDI1.2; also elsewhere on the board
GND: C10.2, C12.2, OLED1.1 (GND), SW1.2, SW2.2, TEMP1.3 (GND), TEMP2.5 (GND), TEMP3.1 (GND), UPDI1.1; also elsewhere on the board
unnamed: D4.2 (A), UPDI1.3

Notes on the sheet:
SOIC-8
Digital
UPDI Header
128x32
Analog
TO-92
0.91" OLED
The digital temperature sensors are optional
Buttons
UPDI might need a serial resistor (4k7). If this resistor is needed, it must be included on the programmer side.
External

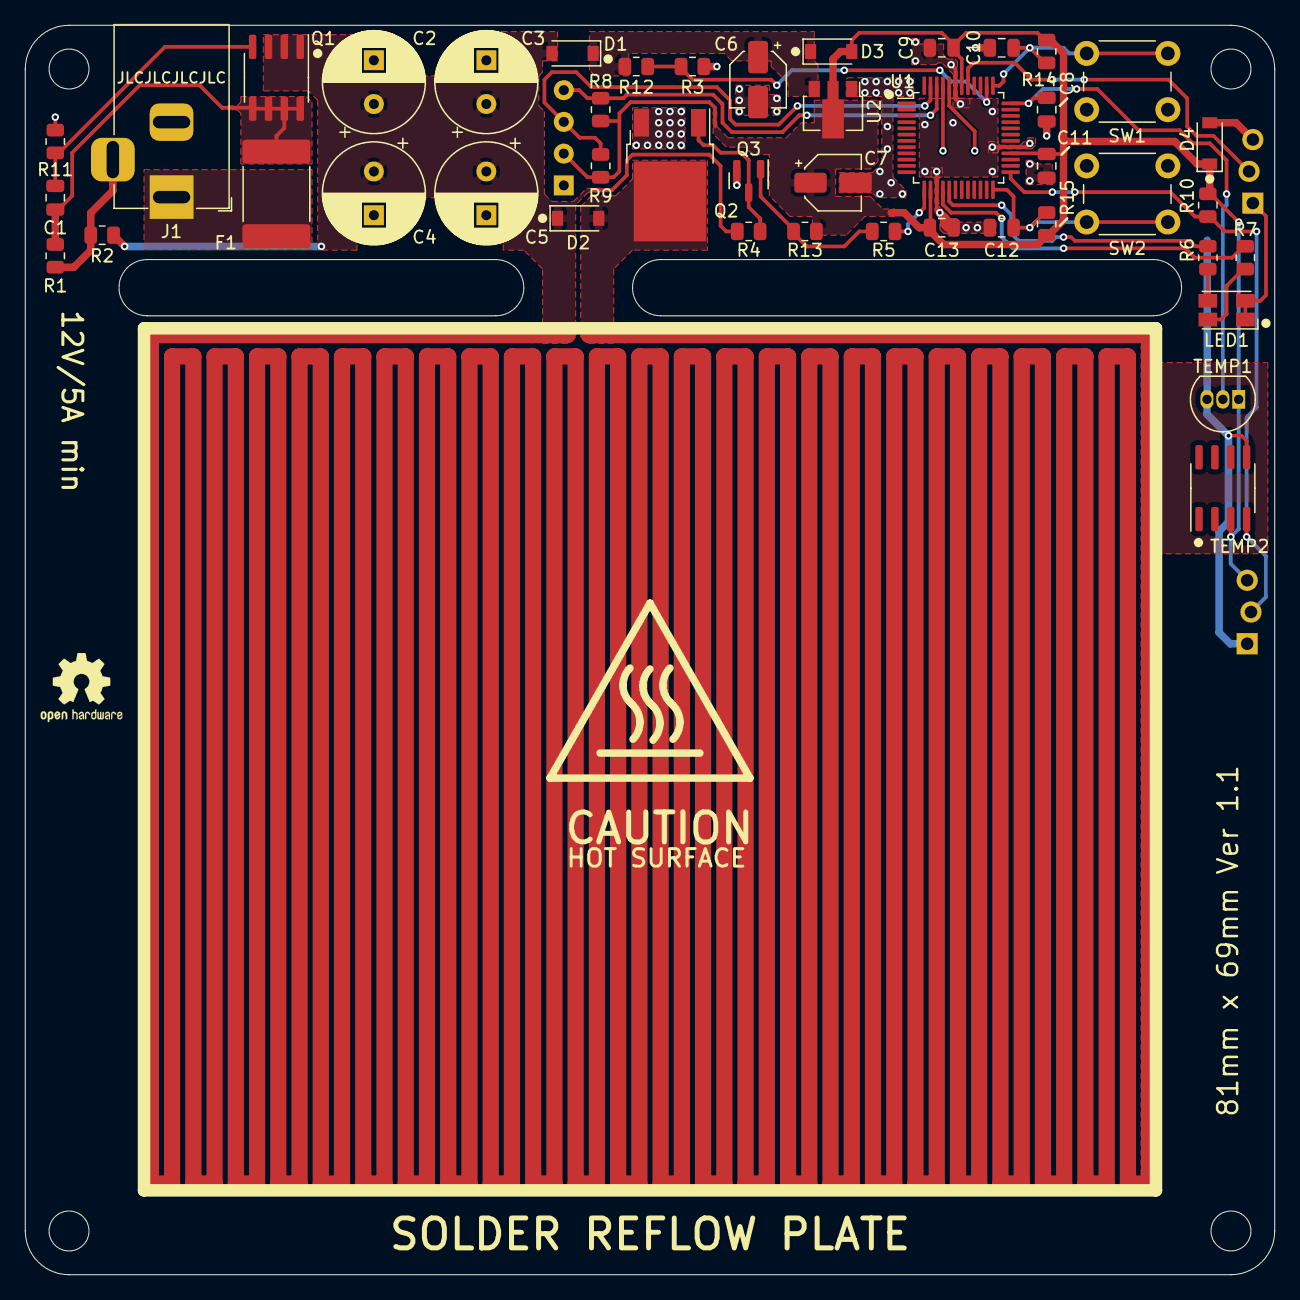
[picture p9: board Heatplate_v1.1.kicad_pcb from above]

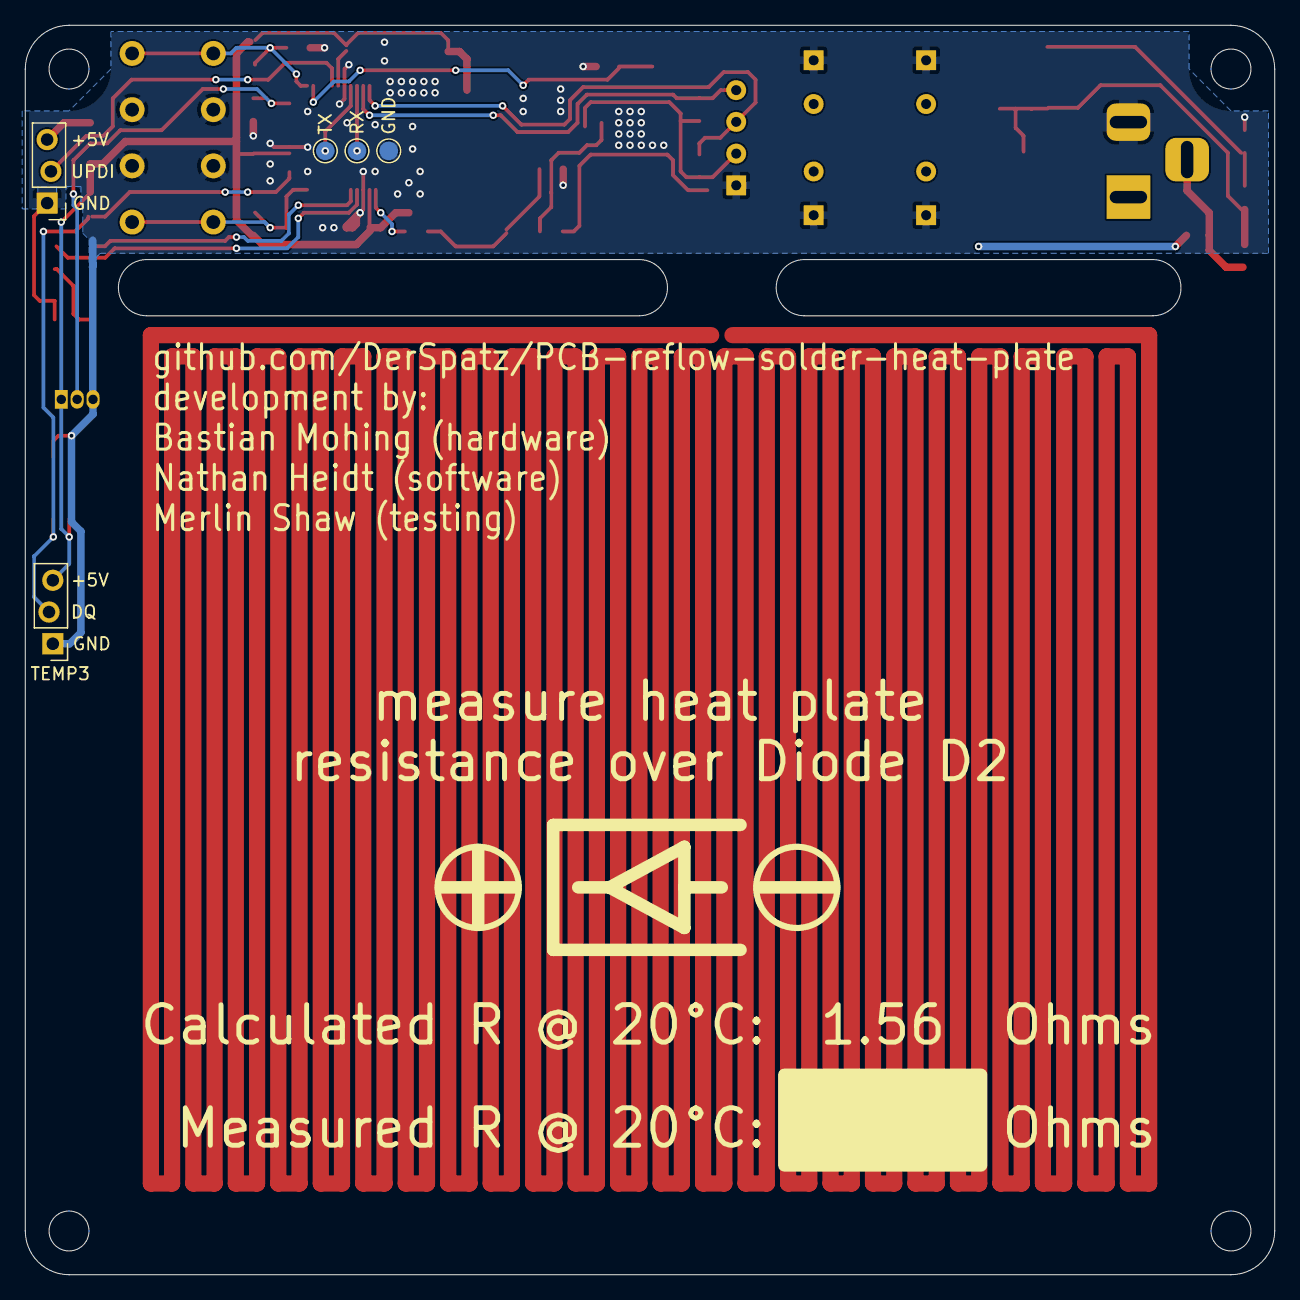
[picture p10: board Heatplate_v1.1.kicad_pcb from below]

Board: 2 copper layers, 100.0 x 100.0 mm, 57 parts (5 on the bottom side), 28 nets.

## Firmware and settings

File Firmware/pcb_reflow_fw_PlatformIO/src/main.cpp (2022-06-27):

/* Solder Reflow Plate Sketch
 *  H/W - Ver Spatz-1.0
 *  S/W - Ver 0.35
 *  by Chris Halsall and Nathan Heidt
 */

/*
 * TODOS:
 * - add digital sensor setup routine if they are detected, but not setup
 * - figure out a method for how to use all the temperature sensors
 * - implement an observer/predictor for the temperature sensors.  Kalman filter
 * time?!?
 */

#include <Adafruit_GFX.h>
#include <Adafruit_SSD1306.h>
#include <DallasTemperature.h>
#include <EEPROM.h>
#include <OneWire.h>
#include <SPI.h>

// Version Definitions
static const PROGMEM float hw = 0.9;
static const PROGMEM float sw = 0.15;

// Screen Definitions
#define SCREEN_WIDTH 128
#define SCREEN_HEIGHT 32
#define SCREEN_ADDRESS 0x3C  // I2C Address
Adafruit_SSD1306 display(SCREEN_WIDTH, SCREEN_HEIGHT, &Wire,
                         -1);  // Create Display

// Pin Definitions
#define MOSFET_PIN PIN_PC3
#define UPSW_PIN PIN_PF3
#define DNSW_PIN PIN_PD4
#define TEMP_PIN PIN_PF2  // A2
#define VCC_PIN PIN_PF4   // A0
#define LED_GREEN_PIN PIN_PC5
#define LED_RED_PIN PIN_PC4
#define ONE_WIRE_BUS PIN_PD5

#define MOSFET_PIN_OFF 255

enum menu_state_t {
  MENU_IDLE,
  MENU_SELECT_PROFILE,
  MENU_HEAT,
  MENU_INC_TEMP,
  MENU_DEC_TEMP
};
enum buttons_state_t {
  BUTTONS_NO_PRESS,
  BUTTONS_BOTH_PRESS,
  BUTTONS_UP_PRESS,
  BUTTONS_DN_PRESS
};
enum single_button_state_t {
  BUTTON_PRESSED,
  BUTTON_RELEASED,
  BUTTON_NO_ACTION
};

// Button interrupt state
volatile single_button_state_t up_button_state = BUTTON_NO_ACTION;
volatile single_button_state_t dn_button_state = BUTTON_NO_ACTION;
volatile unsigned long up_state_change_time = 0;
volatile unsigned long down_state_change_time = 0;

// Temperature Info
byte max_temp_array[] = {140, 150, 160, 170, 180};
byte max_temp_index = 0;
#define MAX_RESISTANCE 10.0
float bed_resistance = 1.88;
#define MAX_AMPERAGE 5.0
#define PWM_VOLTAGE_SCALAR 2.0

// These values were derived using a regression from real world data.
// See the jupyter notebooks for more detail
#define ANALOG_APPROXIMATION_SCALAR 1.612
#define ANALOG_APPROXIMATION_OFFSET -20.517

// EEPROM storage locations
#define CRC_ADDR 0
#define FIRSTTIME_BOOT_ADDR 4
#define TEMP_INDEX_ADDR 5
#define RESISTANCE_INDEX_ADDR 6
#define DIGITAL_TEMP_ID_ADDR 10

// Voltage Measurement Info
#define VOLTAGE_REFERENCE 1.5

// Solder Reflow Plate Logo
static const uint8_t PROGMEM logo[] = {
    0x00, 0x00, 0x00, 0x01, 0x00, 0x00, 0x00, 0x00, 0x00, 0x00, 0x00, 0x00,
    0x00, 0x00, 0x00, 0x00, 0x00, 0x00, 0x00, 0x01, 0x80, 0x00, 0x00, 0x00,
    0x00, 0x00, 0x1f, 0x00, 0x00, 0x00, 0x00, 0x00, 0x00, 0x00, 0x00, 0x01,
    0x80, 0x00, 0x00, 0x1f, 0xc0, 0x00, 0x31, 0x80, 0x00, 0x00, 0x00, 0x00,
    0x1f, 0xe0, 0x03, 0x01, 0x80, 0x00, 0x00, 0x30, 0x70, 0x00, 0x21, 0x80,
    0x00, 0x00, 0x00, 0x00, 0x10, 0x20, 0x03, 0x00, 0xc7, 0x80, 0x00, 0x20,
    0x18, 0xf0, 0x61, 0x80, 0x00, 0x00, 0x00, 0x00, 0x18, 0x00, 0x03, 0x3e,
    0xcc, 0xc0, 0xc0, 0x04, 0x19, 0x98, 0x61, 0x80, 0x00, 0x00, 0x00, 0x00,
    0x1c, 0x01, 0xf3, 0x77, 0xd8, 0xc7, 0xe0, 0x06, 0x33, 0x18, 0x61, 0x8f,
    0x88, 0x00, 0x00, 0x00, 0x06, 0x03, 0x3b, 0x61, 0xd0, 0xc6, 0x00, 0x07,
    0xe2, 0x18, 0x61, 0x98, 0xd8, 0x04, 0x00, 0x00, 0x01, 0xc6, 0x0b, 0x60,
    0xd9, 0x86, 0x00, 0x06, 0x03, 0x30, 0xff, 0xb0, 0x78, 0x66, 0x00, 0x00,
    0x40, 0xe4, 0x0f, 0x60, 0xdf, 0x06, 0x00, 0x07, 0x03, 0xe0, 0x31, 0xe0,
    0x78, 0x62, 0x00, 0x00, 0x40, 0x3c, 0x0f, 0x61, 0xd8, 0x06, 0x00, 0x07,
    0x83, 0x00, 0x31, 0xe0, 0x78, 0x63, 0x00, 0x00, 0x60, 0x36, 0x1b, 0x63,
    0xc8, 0x02, 0x00, 0x02, 0xc1, 0x00, 0x18, 0xb0, 0xcc, 0xe2, 0x00, 0x00,
    0x30, 0x33, 0x3b, 0x36, 0x4e, 0x03, 0x00, 0x02, 0x61, 0xc0, 0x0c, 0x99,
    0xcd, 0xfe, 0x00, 0x00, 0x0f, 0xe1, 0xe1, 0x3c, 0x03, 0xf3, 0x00, 0x02,
    0x38, 0x7e, 0x0c, 0x8f, 0x07, 0x9c, 0x00, 0x00, 0x00, 0x00, 0x00, 0x00,
    0x00, 0x00, 0x00, 0x00, 0x08, 0x00, 0x00, 0x00, 0x00, 0x00, 0x00, 0x00,
    0x00, 0x00, 0x00, 0x18, 0x00, 0x00, 0x00, 0x00, 0x00, 0x00, 0x00, 0x00,
    0x00, 0x00, 0x00, 0x00, 0x7f, 0x84, 0x00, 0x18, 0x00, 0x00, 0x00, 0x00,
    0x00, 0x00, 0x00, 0x00, 0x00, 0x00, 0x00, 0x00, 0xc0, 0xe4, 0x00, 0x18,
    0x38, 0x00, 0x00, 0x00, 0x00, 0x00, 0x00, 0x00, 0x00, 0x00, 0x00, 0x00,
    0x04, 0x3c, 0x3c, 0x18, 0x6c, 0x00, 0x00, 0x00, 0x00, 0x00, 0x00, 0x00,
    0x00, 0x00, 0x00, 0x00, 0x04, 0x1e, 0x06, 0x7f, 0xc6, 0x00, 0x00, 0x00,
    0x00, 0x00, 0x00, 0x00, 0x00, 0x00, 0x00, 0x00, 0x04, 0x3e, 0x03, 0x18,
    0x86, 0x00, 0x00, 0x00, 0x00, 0x00, 0x00, 0x00, 0x00, 0x00, 0x00, 0x00,
    0x04, 0x36, 0x7f, 0x19, 0x8c, 0x00, 0x00, 0x00, 0x00, 0x00, 0x00, 0x00,
    0x00, 0x00, 0x00, 0x00, 0x07, 0xe6, 0xc7, 0x19, 0xf8, 0x00, 0x00, 0x00,
    0x00, 0x00, 0x00, 0x00, 0x00, 0x00, 0x00, 0x00, 0x06, 0x07, 0x83, 0x18,
    0x80, 0x00, 0x00, 0x00, 0x00, 0x00, 0x00, 0x00, 0x00, 0x00, 0x00, 0x00,
    0x06, 0x07, 0x81, 0x18, 0xc0, 0x00, 0x00, 0x00, 0x00, 0x00, 0x00, 0x00,
    0x00, 0x00, 0x00, 0x00, 0x06, 0x06, 0xc3, 0x98, 0x70, 0x00, 0x00, 0x00,
    0x00, 0x00, 0x00, 0x00, 0x00, 0x00, 0x00, 0x00, 0x02, 0x04, 0x7e, 0x08,
    0x3f, 0x80, 0x00, 0x00, 0x00, 0x00, 0x00, 0x00, 0x00, 0x00, 0x00, 0x00};
static const uint8_t logo_width = 128;
static const uint8_t logo_height = 27;

// Heating Animation
static const uint8_t PROGMEM heat_animate[] = {
    0b00000001, 0b00000000, 0b00000001, 0b10000000, 0b00000001, 0b10000000,
    0b00000001, 0b01000000, 0b00000010, 0b01000000, 0b00100010, 0b01000100,
    0b00100100, 0b00100100, 0b01010101, 0b00100110, 0b01001001, 0b10010110,
    0b10000010, 0b10001001, 0b10100100, 0b01000001, 0b10011000, 0b01010010,
    0b01000100, 0b01100010, 0b00100011, 0b10000100, 0b00011000, 0b00011000,
    0b00000111, 0b11100000};
static const uint8_t heat_animate_width = 16;
static const uint8_t heat_animate_height = 16;

// Tick
static const uint8_t PROGMEM tick[] = {
    0b00000000, 0b00000100, 0b00000000, 0b00001010, 0b00000000, 0b00010101,
    0b00000000, 0b00101010, 0b00000000, 0b01010100, 0b00000000, 0b10101000,
    0b00000001, 0b01010000, 0b00100010, 0b10100000, 0b01010101, 0b01000000,
    0b10101010, 0b10000000, 0b01010101, 0b00000000, 0b00101010, 0b00000000,
    0b00010100, 0b00000000, 0b00001000, 0b00000000, 0b01111111, 0b11100000};
static const uint8_t tick_width = 16;
static const uint8_t tick_height = 15;

// This needs to be specified or the compiler will fail as you can't initialize
// a flexible array member in a nested context
#define MAX_PROFILE_LENGTH 8

// TODO(HEIDT) may need to switch away from floats for speed/sizeA
struct solder_profile_t {
  uint8_t points;
  float seconds[MAX_PROFILE_LENGTH];
  float fraction[MAX_PROFILE_LENGTH];
};

// TODO(HEIDT) how to adjust for environments where the board starts hot or
// cold? profiles pulled from here:
// https://www.compuphase.com/electronics/reflowsolderprofiles.htm#_
#define NUM_PROFILES 2
const static solder_profile_t profiles[NUM_PROFILES] = {
    {.points = 4,
     .seconds = {90, 180, 240, 260},
     .fraction = {.65, .78, 1.00, 1.00}},
    {.points = 2, .seconds = {162.0, 202.0}, .fraction = {.95, 1.00}}};

// temperature must be within this range to move on to next step
#define TARGET_TEMP_THRESHOLD 2.5

// PID values
float kI = 0.2;
float kD = 0.25;
float kP = 8.0;
float I_clip = 220;
float error_I = 0;

// Optional temperature sensor
OneWire oneWire(ONE_WIRE_BUS);
DallasTemperature sensors(&oneWire);
int sensor_count = 0;
DeviceAddress temp_addresses[3];

#define DEBUG

#ifdef DEBUG
#define debugprint(x) Serial.print(x);
#define debugprintln(x) Serial.println(x);
#else
#define debugprint(x)
#define debugprintln(x)
#endif

// -------------------- Function prototypes -----------------------------------
void inline heatAnimate(int &x, int &y, float v, float t, float target_temp);

// -------------------- General functions ----------------------------------

void dnsw_change_isr() {
  dn_button_state = BUTTON_PRESSED;
  down_state_change_time = millis();
}

void upsw_change_isr() {
  up_button_state = BUTTON_PRESSED;
  up_state_change_time = millis();
}

void setCRC(uint32_t new_crc) { EEPROM.put(CRC_ADDR, new_crc); }

uint32_t eepromCRC(void) {
  static const uint32_t crc_table[16] = {
      0x00000000, 0x1db71064, 0x3b6e20c8, 0x26d930ac, 0x76dc4190, 0x6b6b51f4,
      0x4db26158, 0x5005713c, 0xedb88320, 0xf00f9344, 0xd6d6a3e8, 0xcb61b38c,
      0x9b64c2b0, 0x86d3d2d4, 0xa00ae278, 0xbdbdf21c};
  uint32_t crc = ~0L;
  // Skip first 4 bytes of EEPROM as thats where we store the CRC
  for (int index = 4; index < EEPROM.length(); ++index) {
    crc = crc_table[(crc ^ EEPROM[index]) & 0x0f] ^ (crc >> 4);
    crc = crc_table[(crc ^ (EEPROM[index] >> 4)) & 0x0f] ^ (crc >> 4);
    crc = ~crc;
  }

  return crc;
}

void updateCRC() {
  uint32_t new_crc = eepromCRC();
  setCRC(new_crc);
}

bool validateCRC() {
  uint32_t stored_crc;
  EEPROM.get(CRC_ADDR, stored_crc);
  uint32_t calculated_crc = eepromCRC();
  debugprint("got CRCs, stored: ");
  debugprint(stored_crc);
  debugprint(", calculated: ");
  debugprintln(calculated_crc);
  return stored_crc == calculated_crc;
}

inline void setupSensors() {
  sensors.begin();
  sensor_count = sensors.getDeviceCount();
  debugprint("Looking for sensors, found: ");
  debugprintln(sensor_count);
  for (int i = 0; i < min(sensor_count, sizeof(temp_addresses)); i++) {
    sensors.getAddress(temp_addresses[i], i);
  }
}

inline void setFastPwm() { analogWriteFrequency(64); }

inline void setVREF() { analogReference(INTERNAL1V5); }

inline bool isFirstBoot() {
  uint8_t first_boot = EEPROM.read(FIRSTTIME_BOOT_ADDR);
  debugprint("Got first boot flag: ");
  debugprintln(first_boot);
  return first_boot != 1;
}

inline void setFirstBoot() {
  EEPROM.write(FIRSTTIME_BOOT_ADDR, 1);
  updateCRC();
}

inline float getResistance() {
  float f;
  return EEPROM.get(RESISTANCE_INDEX_ADDR, f);
  return f;
}

inline void setResistance(float resistance) {
  EEPROM.put(RESISTANCE_INDEX_ADDR, resistance);
  updateCRC();
}

inline void setMaxTempIndex(int index) {
  EEPROM.update(TEMP_INDEX_ADDR, index);
  updateCRC();
}

inline int getMaxTempIndex(void) {
  return EEPROM.read(TEMP_INDEX_ADDR) % sizeof(max_temp_array);
}

float getTemp() {
  debugprint("Temps: ");
  float t = 0;
  for (byte i = 0; i < 100; i++) {  // Poll TEMP_PIN reading 100 times
    t = t + analogRead(TEMP_PIN);
  }
  t /= 100.0;                       // average
  t *= VOLTAGE_REFERENCE / 1024.0;  // voltage
  // conversion to temp, consult datasheet:
  // https://www.ti.com/document-viewer/LMT85/datasheet/detailed-description#snis1681040
  // this is optimized for 25C to 150C
  // TODO(HEIDT) this is linearized and innacurate, could probably use the
  // nonlinear functions without much overhead.
  t = (t - 1.365) / ((.301 - 1.365) / (150.0 - 25.0)) + 25.0;

  // The analog sensor is too far from the bed for an accurate reading
  // this simple function estimates the true bed temperature based off the
  // thermal gradient
  float estimated_temp =
      t * ANALOG_APPROXIMATION_SCALAR + ANALOG_APPROXIMATION_OFFSET;
  debugprint(estimated_temp);
  debugprint(" ");

  sensors.requestTemperatures();
  for (int i = 0; i < sensor_count; i++) {
    float temp_in = sensors.getTempC(temp_addresses[i]);
    debugprint(temp_in);
    debugprint(" ");
  }
  debugprintln();

  return max(t, estimated_temp);
}

float getVolts() {
  float v = 0;
  for (byte i = 0; i < 20; i++) {  // Poll Voltage reading 20 times
    v = v + analogRead(VCC_PIN);
  }
  v /= 20;

  float vin = (v / 1023.0) * 1.5;
  debugprint("voltage at term: ");
  debugprintln(vin);
  vin = (vin / 0.090981) + 0.3;
  return vin;
}

#define BUTTON_PRESS_TIME 50
buttons_state_t getButtonsState() {
  single_button_state_t button_dn;
  single_button_state_t button_up;
  unsigned long button_dn_time;
  unsigned long button_up_time;

  noInterrupts();
  button_dn = dn_button_state;
  button_up = up_button_state;
  button_dn_time = down_state_change_time;
  button_up_time = up_state_change_time;
  interrupts();

  unsigned long cur_time = millis();
  buttons_state_t state = BUTTONS_NO_PRESS;

  if (button_dn == BUTTON_PRESSED && button_up == BUTTON_PRESSED &&
      abs(button_dn_time - button_up_time) < BUTTON_PRESS_TIME) {
    if (cur_time - button_dn_time > BUTTON_PRESS_TIME &&
        cur_time - button_up_time > BUTTON_PRESS_TIME) {
      state = BUTTONS_BOTH_PRESS;
      noInterrupts();
      dn_button_state = BUTTON_NO_ACTION;
      up_button_state = BUTTON_NO_ACTION;
      interrupts();
    }
  } else if (button_up == BUTTON_PRESSED &&
             cur_time - button_up_time > BUTTON_PRESS_TIME) {
    state = BUTTONS_UP_PRESS;
    noInterrupts();
    up_button_state = BUTTON_NO_ACTION;
    interrupts();
  } else if (button_dn == BUTTON_PRESSED &&
             cur_time - button_dn_time > BUTTON_PRESS_TIME) {
    state = BUTTONS_DN_PRESS;
    noInterrupts();
    dn_button_state = BUTTON_NO_ACTION;
    interrupts();
  }

  return state;
}

// -------------------- UI Parts -----------------------------------

inline void clearMainMenu() {
  display.clearDisplay();
  display.setTextSize(1);
  display.drawRoundRect(0, 0, 83, 32, 2, SSD1306_WHITE);
}

inline void getResistanceFromUser() {
  float resistance = 1.88;
  while (1) {
    clearMainMenu();
    display.setCursor(3, 4);
    display.print(F("Resistance"));
    display.drawLine(3, 12, 79, 12, SSD1306_WHITE);
    display.setCursor(3, 14);
    display.print(F("UP/DN: change"));
    display.setCursor(3, 22);
    display.print(F("BOTH: choose"));
    buttons_state_t button = getButtonsState();
    if (button == BUTTONS_UP_PRESS) {
      resistance += 0.01;
    } else if (button == BUTTONS_DN_PRESS) {
      resistance -= 0.01;
    } else if (button == BUTTONS_BOTH_PRESS) {
      setResistance(resistance);
      return;
    }
    resistance = constrain(resistance, 0, MAX_RESISTANCE);

    display.setCursor(90, 12);
    display.print(resistance);
    display.display();
  }
}

inline void doSetup() {
  debugprintln("Performing setup");
  // TODO(HEIDT) show an info screen if we're doing firstime setup or if memory
  // is corrupted

  getResistanceFromUser();
  // TODO(HEIDT) do a temperature module setup here

  setFirstBoot();
}

void showLogo() {
  unsigned long start_time = millis();
  display.begin(SSD1306_SWITCHCAPVCC, SCREEN_ADDRESS);
  while (start_time + 2000 > millis()) {
    display.clearDisplay();
    display.setTextSize(1);
    display.setTextColor(SSD1306_WHITE);
    display.setCursor(0, 0);
    display.drawBitmap(0, 0, logo, logo_width, logo_height, SSD1306_WHITE);
    display.setCursor(80, 16);
    display.print(F("S/W V"));
    display.print(sw, 1);
    display.setCursor(80, 24);
    display.print(F("H/W V"));
    display.print(hw, 1);
    display.display();
    buttons_state_t cur_button = getButtonsState();
    // If we press both buttons during boot, we'll enter the setup process
    if (cur_button == BUTTONS_BOTH_PRESS) {
      doSetup();
      return;
    }
  }
}

inline void displayProfileRight(int8_t cur_profile) {
  int cur_x = 90;
  int cur_y = 30;
  // start at x=90, go to SCREEN_WIDTH-8, save 6 pixels for cooldown
  float x_dist = SCREEN_WIDTH - 90 - 8;
  display.setCursor(cur_x, cur_y);
  float total_seconds =
      (int)profiles[cur_profile].seconds[profiles[cur_profile].points - 1];

  for (int i = 0; i < profiles[cur_profile].points; i++) {
    int x_next =
        (int)((profiles[cur_profile].seconds[i] / total_seconds) * x_dist) + 90;
    int y_next = 30 - (int)(profiles[cur_profile].fraction[i] * 28.0);
    display.drawLine(cur_x, cur_y, x_next, y_next, SSD1306_WHITE);
    cur_x = x_next;
    cur_y = y_next;
  }
  // draw down to finish TEMP_PIN
  display.drawLine(cur_x, cur_y, SCREEN_WIDTH - 2, 30, SSD1306_WHITE);
}

inline uint8_t getProfile() {
  uint8_t cur_profile = 0;
  while (1) {
    clearMainMenu();
    display.setCursor(3, 4);
    display.print(F("Pick profile"));
    display.drawLine(3, 12, 79, 12, SSD1306_WHITE);
    display.setCursor(3, 14);
    display.print(F(" UP/DN: cycle"));
    display.setCursor(3, 22);
    display.print(F(" BOTH: choose"));
    buttons_state_t cur_button = getButtonsState();
    if (cur_button == BUTTONS_BOTH_PRESS) {
      clearMainMenu();
      return cur_profile;
    } else if (cur_button == BUTTONS_DN_PRESS) {
      cur_profile--;
    } else if (cur_button == BUTTONS_UP_PRESS) {
      cur_profile++;
    }
    cur_profile %= NUM_PROFILES;
    displayProfileRight(cur_profile);
    display.display();
  }
}

void cancelledTimer() {  // Cancelled via 5 minute Time Limit
  // Initiate Swap Display
  int x = 0;    // Display change counter
  int y = 150;  // Display change max (modulused below)

  // Wait to return on any button press
  while (getButtonsState() == BUTTONS_NO_PRESS) {
    // Update Display
    display.clearDisplay();
    display.drawRoundRect(22, 0, 84, 32, 2, SSD1306_WHITE);
    display.setCursor(25, 4);
    display.print(F("  TIMED OUT"));
    display.drawLine(25, 12, 103, 12, SSD1306_WHITE);

    // Swap Main Text
    if (x < (y * 0.3)) {
      display.setCursor(25, 14);
      display.println(" Took longer");
      display.setCursor(25, 22);
      display.println(" than 5 mins");
    } else if (x < (y * 0.6)) {
      display.setCursor(28, 14);
      display.println("Try a higher");
      display.setCursor(25, 22);
      display.println(" current PSU");
    } else {
      display.setCursor(25, 14);
      display.println(" Push button");
      display.setCursor(25, 22);
      display.println("  to return");
    }
    x = (x + 1) % y;  // Display change increment and modulus

    display.setTextSize(3);
    display.setCursor(5, 4);
    display.print(F("!"));
    display.setTextSize(3);
    display.setCursor(108, 4);
    display.print(F("!"));
    display.setTextSize(1);
    display.display();
    delay(50);
  }
}

inline void showHeatMenu(byte max_temp) {
  display.clearDisplay();
  display.setTextSize(2);
  display.setCursor(22, 4);
  display.print(F("HEATING"));
  display.setTextSize(1);
  display.setCursor(52, 24);
  display.print(max_temp);
  display.print(F("C"));
  display.display();
}

void stepPID(float target_temp, float current_temp, float last_temp, float dt,
             int min_pwm) {
  float error = target_temp - current_temp;
  float D = (current_temp - last_temp) / dt;

  error_I += error * dt * kI;
  error_I = constrain(error_I, 0, I_clip);

  // PWM is inverted so 0 duty is 100% power
  float PWM = 255.0 - (error * kP + D * kD + error_I);
  PWM = constrain(PWM, min_pwm, 255);

  debugprintln("PID");
  debugprintln(dt);
  debugprintln(error);
  debugprintln(error_I);
  debugprint("PWM: ");
  debugprintln(PWM);
  analogWrite(MOSFET_PIN, (int)PWM);
}

bool heat(byte max_temp, int profile_index) {
  // Heating Display
  showHeatMenu(max_temp);
  delay(3000);

  float t;  // Used to store current temperature
  float v;  // Used to store current voltage

  unsigned long profile_max_time = millis() / 1000 + (8 * 60);
  unsigned long step_start_time = (millis() / 1000);
  int current_step = 0;

  // Other control variables
  int x = 0;   // Heat Animate Counter
  int y = 80;  // Heat Animate max (modulused below)

  float start_temp = getTemp();
  float goal_temp = profiles[profile_index].fraction[0] * max_temp;
  float step_runtime = profiles[profile_index].seconds[0];
  float last_time = 0;
  float last_temp = getTemp();
  error_I = 0;

  while (1) {
    // Cancel heat, don't even wait for uppress so we don't risk missing it
    // during the loop
    if (getButtonsState() != BUTTONS_NO_PRESS) {
      analogWrite(MOSFET_PIN, MOSFET_PIN_OFF);
      debugprintln("cancelled");
      return 0;
    }

    // Check Heating not taken more than 8 minutes
    if (millis() / 1000 > profile_max_time) {
      analogWrite(MOSFET_PIN, MOSFET_PIN_OFF);
      debugprintln("exceeded time");
      cancelledTimer();
      return 0;
    }

    // Measure Values
    // TODO(HEIDT) getting the temperature from the digital sensors is by far
    // the slowest part of this loop. figure out an approach that allows control
    // faster than sensing
    t = getTemp();
    v = getVolts();
    float max_possible_amperage = v / bed_resistance;
    // TODO(HEIDT) approximate true resistance based on cold resistance and
    // temperature
    float vmax = (MAX_AMPERAGE * bed_resistance) * PWM_VOLTAGE_SCALAR;
    int min_PWM = 255 - ((vmax * 255.0) / v);
    min_PWM = constrain(min_PWM, 0, 255);
    debugprint("Min PWM: ");
    debugprintln(min_PWM);
    debugprintln(bed_resistance);

    // Determine what target temp is and PID to it
    float time_into_step = ((float)millis() / 1000.0) - (float)step_start_time;
    float target_temp =
        min(((goal_temp - start_temp) * (time_into_step / step_runtime)) +
                start_temp,
            goal_temp);

    // TODO(HEIDT) PID for a ramp will always lag, other options may be better
    stepPID(target_temp, t, last_temp, time_into_step - last_time, min_PWM);
    last_time = time_into_step;

    // if we finish the step timewise
    if (time_into_step >= step_runtime) {
      // and if we're within the goal temperature of the step
      if (abs(t - goal_temp) < TARGET_TEMP_THRESHOLD) {
        // move onto the next step in the profile
        current_step++;
        // if that was the last step, we're done!
        if (current_step == profiles[profile_index].points) {
          analogWrite(MOSFET_PIN, MOSFET_PIN_OFF);
          return 1;
        }
        // otherwise, get the next goal temperature and runtime, and do the
        // process again
        last_time = 0.0;
        start_temp = t;
        goal_temp = profiles[profile_index].fraction[current_step] * max_temp;
        step_runtime = profiles[profile_index].seconds[current_step] -
                       profiles[profile_index].seconds[current_step - 1];
        step_start_time = millis() / 1000.0;
      }
    }

    heatAnimate(x, y, v, t, target_temp);
  }
}
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
void loop() {
  // Not used
}

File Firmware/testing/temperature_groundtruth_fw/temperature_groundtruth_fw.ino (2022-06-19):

#include <Adafruit_MAX31865.h>

// Use software SPI: CS, DI, DO, CLK
Adafruit_MAX31865 thermo = Adafruit_MAX31865(3, 4, 5, 6);

// The value of the Rref resistor. Use 430.0 for PT100 and 4300.0 for PT1000
#define RREF      430.0
// The 'nominal' 0-degrees-C resistance of the sensor
// 100.0 for PT100, 1000.0 for PT1000
#define RNOMINAL  100.0


void setup() {
    Serial.begin(115200);
    Serial1.begin(9600);
    thermo.begin(MAX31865_3WIRE);  // set to 2WIRE or 4WIRE as necessary

}

void loop() {


  uint8_t fault = thermo.readFault();
  if (fault) {
    Serial.print("Fault 0x"); Serial.println(fault, HEX);
    if (fault & MAX31865_FAULT_HIGHTHRESH) {
      Serial.println("RTD High Threshold"); 
    }
    if (fault & MAX31865_FAULT_LOWTHRESH) {
      Serial.println("RTD Low Threshold"); 
    }
    if (fault & MAX31865_FAULT_REFINLOW) {
      Serial.println("REFIN- > 0.85 x Bias"); 
    }
    if (fault & MAX31865_FAULT_REFINHIGH) {
      Serial.println("REFIN- < 0.85 x Bias - FORCE- open"); 
    }
    if (fault & MAX31865_FAULT_RTDINLOW) {
      Serial.println("RTDIN- < 0.85 x Bias - FORCE- open"); 
    }
    if (fault & MAX31865_FAULT_OVUV) {
      Serial.println("Under/Over voltage"); 
    }
    thermo.clearFault();
  }

    String s;
    if (Serial1.available()) {
        s = Serial1.readStringUntil('\n');
        Serial.println(s);
    }

    if (s.indexOf("Temps") >= 0) {
        Serial.print("Groundtruth ");
        Serial.println(thermo.temperature(RNOMINAL, RREF));
    }
}

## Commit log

2022-03-18 Add files via upload
    added v0.9
    [Heatplate_v0.9.kicad_pcb, Heatplate_v0.9.kicad_sch, PERIPHERALS.kicad_sch]
2022-03-19 Add files via upload
    status LEDs added
    [Heatplate_v0.9.kicad_pcb, Heatplate_v0.9.kicad_sch, PERIPHERALS.kicad_sch]
2022-03-19 error in LED2 footprint fixed
    [Heatplate_v0.9.kicad_pcb, Heatplate_v0.9.kicad_sch]
2022-03-19 Added first time startup and CRC checks. Added better button handling
2022-03-19 Minor features and additions, added max current management
2022-04-15 Changed pins, added fixes for min heat, added interrupt based buttons
    [pcb_reflow_fw.ino]
2022-04-16 Fixed second temperature point bug
    [pcb_reflow_fw.ino]
2022-04-22 Added better pin debouncing, voltage references, python parsing, groundtruth measurements
2022-05-30 added "JLCJLCJLCJLC"
    [Heatplate_v1.0.kicad_pcb]
2022-05-31 better solder profiles
2022-05-31 Version fixes and cleanup
    [pcb_reflow_fw.ino, temperature_groundtruth_fw.ino]
2022-05-31 Changed one wire bus pin
2022-06-19 Update pcb_reflow_fw.ino
    changed LED pin definitions, changed resistance settings to smaller steps
2022-06-27 Restored Arduino based firmware
2022-06-27 Add files via upload
    changed some small things for easier manufacturing, adjusted heat plate resistance
    [Heatplate_v1.1.kicad_pcb, Heatplate_v1.1.kicad_sch, PERIPHERALS.kicad_sch]
2022-06-27 minor change to BOM
    [Heatplate_v1.1.kicad_pcb, Heatplate_v1.1.kicad_sch]
2022-08-08 changed R4 from 1k to 4k7
    The current flow through this resistor was too high, so it got too hot.
    [Heatplate_v1.1.kicad_pcb, Heatplate_v1.1.kicad_sch]
